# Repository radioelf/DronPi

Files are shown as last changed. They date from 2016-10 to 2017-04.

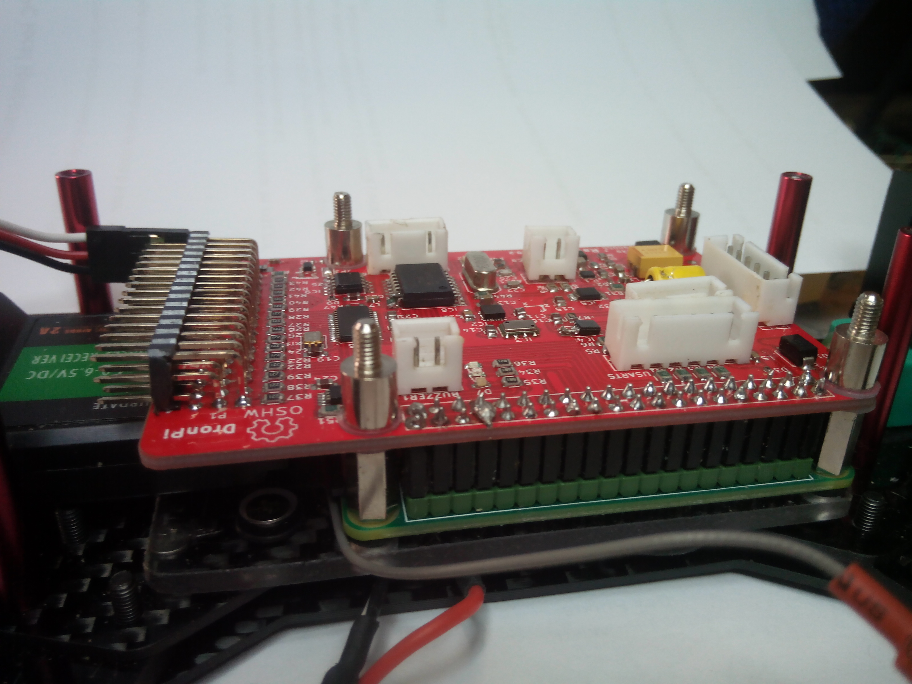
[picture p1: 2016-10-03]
images/IMG_20160930_155603.jpg

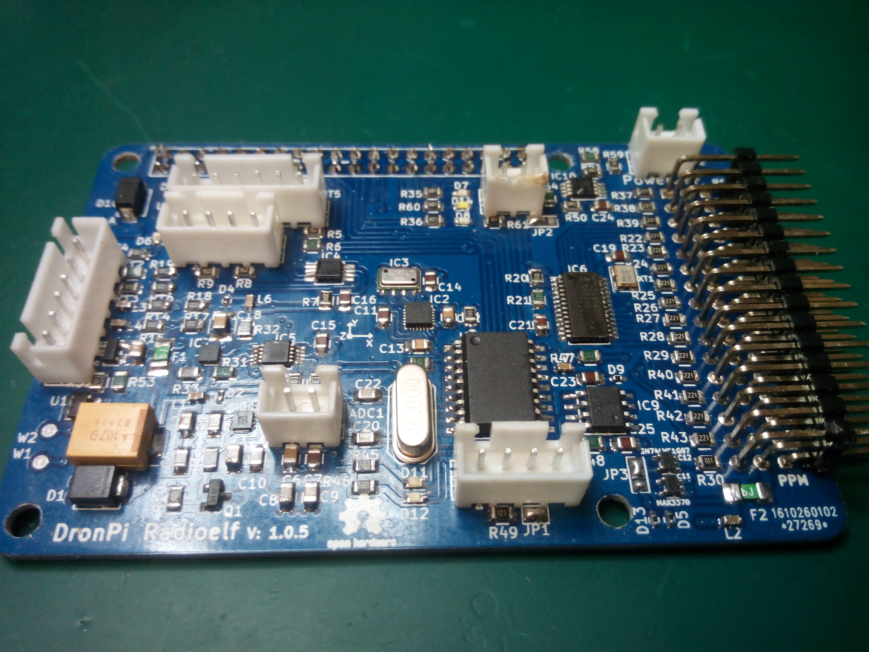
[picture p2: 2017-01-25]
images/IMG_20170104_161110.jpg

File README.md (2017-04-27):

# DronPi 
Placa sensores para [ardupilot](https://github.com/ArduPilot) y Raspberry o [DuePi](https://github.com/radioelf/Arduino-Due-mod-for-GPIO-compatible-Raspberry-Pi)

Sensores:  
    -***MS5611*** Sensor de presión barométrica (Bus SPI)   
    -***MPU9250*** 	Giroscopio/Acelerómetro/Compás interno/9-AXIS (Bus SPI)   
    -***MCP2515*** CAN Bus (Bus SPI)  
    -***ADS1115*** ADC 16bits (Bus I2C) dirección 0x48, canal 0 tensión, canal 1 intensidad  
    -***PCA9685*** Generador de PWM (Bus I2c) dirección 0x40 y 0x70(ALLCALL)

Periféricos: zumbador, RS-232, i2C, PowerOOF, PPM S-BUS, ADC, Can-Bus, HATs (Hardware Attached on Top)

http://radioelf.blogspot.com.es/  
https://www.youtube.com/watch?v=Fd6dcFx_-Ns (test..)

1/01/17
Changed IC12 SN74LVC1G07 by SN74AHC1G04 (to use S-bus)

## Creative Commons License Disclaimer

UNLESS OTHERWISE MUTUALLY AGREED TO BY THE PARTIES IN WRITING, LICENSOR OFFERS THE WORK AS-IS AND MAKES NO REPRESENTATIONS OR WARRANTIES OF ANY KIND CONCERNING THE WORK, EXPRESS, IMPLIED, STATUTORY OR OTHERWISE, INCLUDING, WITHOUT LIMITATION, WARRANTIES OF TITLE, MERCHANTIBILITY, FITNESS FOR A PARTICULAR PURPOSE, NONINFRINGEMENT, OR THE ABSENCE OF LATENT OR OTHER DEFECTS, ACCURACY, OR THE PRESENCE OF ABSENCE OF ERRORS, WHETHER OR NOT DISCOVERABLE. SOME JURISDICTIONS DO NOT ALLOW THE EXCLUSION OF IMPLIED WARRANTIES, SO SUCH EXCLUSION MAY NOT APPLY TO YOU. EXCEPT TO THE EXTENT REQUIRED BY APPLICABLE LAW, IN NO EVENT WILL LICENSOR BE LIABLE TO YOU ON ANY LEGAL THEORY FOR ANY SPECIAL, INCIDENTAL, CONSEQUENTIAL, PUNITIVE OR EXEMPLARY DAMAGES ARISING OUT OF THIS LICENSE OR THE USE OF THE WORK, EVEN IF LICENSOR HAS BEEN ADVISED OF THE POSSIBILITY OF SUCH DAMAGES.

http://creativecommons.org/licenses/by-sa/3.0/

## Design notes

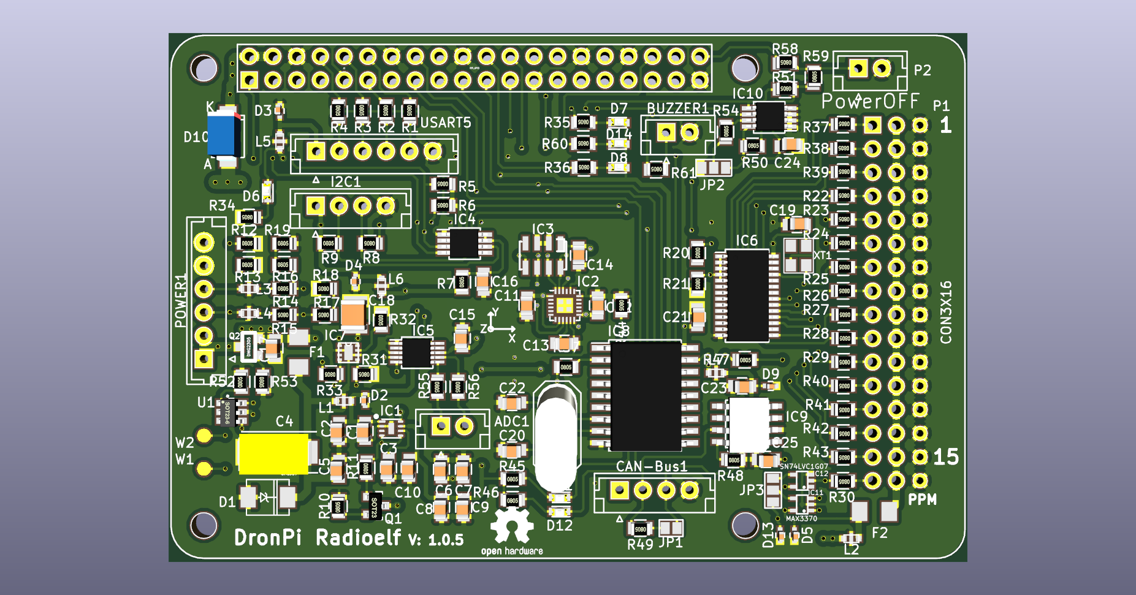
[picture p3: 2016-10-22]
images/dronPi.png

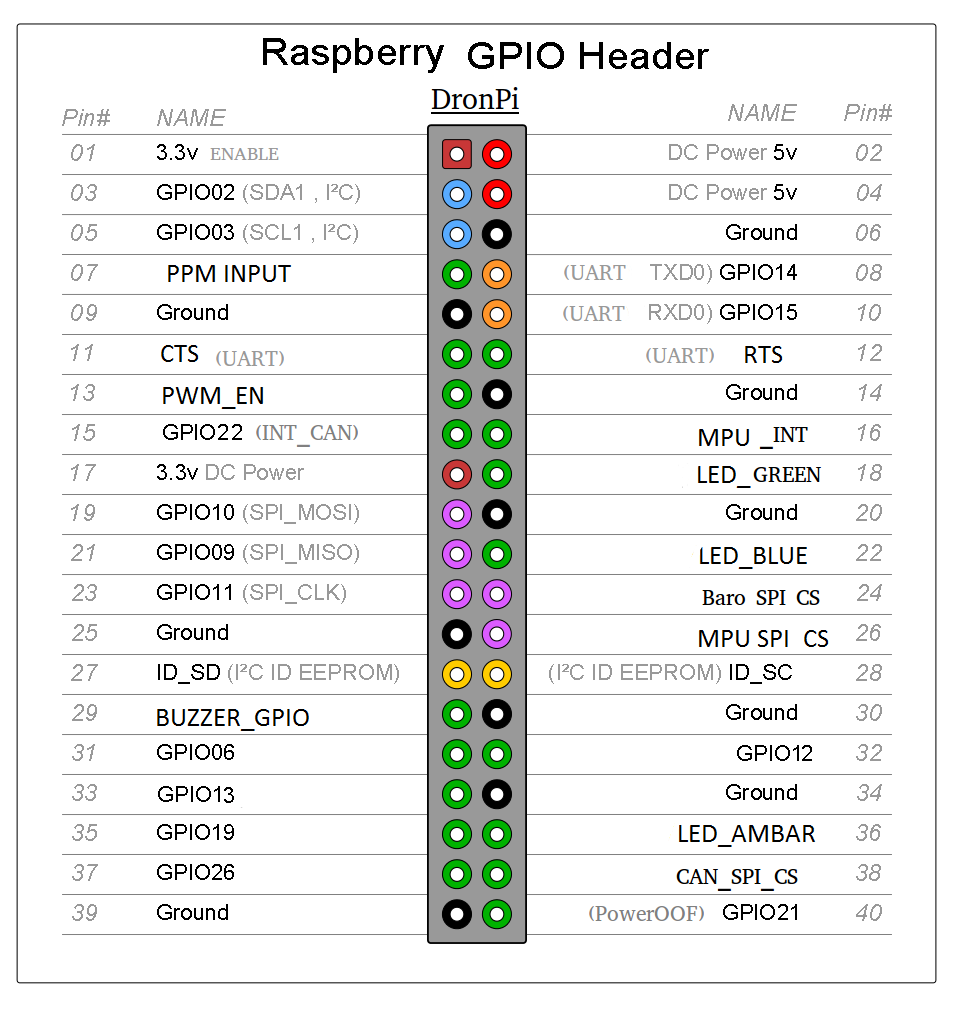
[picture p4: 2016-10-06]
images/GPIO_DronPi.png

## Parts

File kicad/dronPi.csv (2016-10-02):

Reference | Value | Footprint | Datasheet
M1 | OSHW-LOGOS | Symbols:OSHW-Logo2_7.3x6mm_SilkScreen
J1 | RPi_GPIO | dronpi:raspberrypi2
IC7 | BQ24315 | dronpi:BQ24313_DSG_8
R32 | 24K | Resistors_SMD:R_0805
R31 | 10K | Resistors_SMD:R_0805
R33 | 1M | Resistors_SMD:R_0805
C18 | 100uF | Capacitors_SMD:C_1210
W2 | REG_FAULT | Measurement_Points:Measurement_Point_Round-SMD-Pad_Small
W1 | REG_CE | Measurement_Points:Measurement_Point_Round-SMD-Pad_Small
IC4 | PCA9306 | Housings_SSOP:MSOP-8_3x3mm_Pitch0.65mm
R7 | 200K | Resistors_SMD:R_0805
R6 | 1K5 | Resistors_SMD:R_0805
R5 | 1K5 | Resistors_SMD:R_0805
R8 | 1K5 | Resistors_SMD:R_0805
R9 | 1K5 | Resistors_SMD:R_0805
C16 | 100nF | Capacitors_SMD:C_0805
D4 | PESD0402-140 | Capacitors_SMD:C_0402
L6 | KNH16C104DA5TS | dronpi:KYOCERA-KNH16-DA
I2C1 | JST_4PIN | Connectors_JST:JST_EH_B04B-EH-A_04x2.50mm_Straight
D1 | SMBJ5V | Tinkerforge:DO-214AA
C4 | 220uF | Capacitors_Tantalum_SMD:TantalC_SizeD_EIA-7343_Reflow
C5 | 100nF | Capacitors_SMD:C_0805
IC1 | MIC5332 | awallin:MLF-8-1EP
C3 | 2u2F | Capacitors_SMD:C_0805
C6 | 22uF | Capacitors_SMD:C_0805
C7 | 100nF | Capacitors_SMD:C_0805
C8 | 1uF | Capacitors_SMD:C_0805
C9 | 22uF | Capacitors_SMD:C_0805
C10 | 100nF | Capacitors_SMD:C_0805
C2 | 10uF | Capacitors_SMD:C_0805
C1 | 100nF | Capacitors_SMD:C_0805
F1 | 0ZCA0035FF2G | Fuse_Holders_and_Fuses:Fuse_SMD1206_Wave
L1 | KNH16C104DA5TS | dronpi:KYOCERA-KNH16-DA
L2 | KNH16C104DA5TS | dronpi:KYOCERA-KNH16-DA
D2 | PESD0402-140 | Capacitors_SMD:C_0402
D5 | PESD0402-140 | Capacitors_SMD:C_0402
Q1 | MMBT3906LT1 | TO_SOT_Packages_SMD:SOT-23
R11 | 1k8 | Resistors_SMD:R_0805
R10 | 10R | Resistors_SMD:R_0805
POWER1 | JST_6PIN | Connectors_JST:JST_EH_B06B-EH-A_06x2.50mm_Straight
C17 | 22uF | Capacitors_SMD:C_0805
Q2 | DMG2305 | Tinkerforge:SOT23-3
U1 | DMMT5401 | TO_SOT_Packages_SMD:SOT-23-6
R52 | 47k | Resistors_SMD:R_0805
R53 | 47K | Resistors_SMD:R_0805
D10 | STPS1L30A | Diodes_SMD:SMA_Standard
R59 | 10k | Resistors_SMD:R_0805
R58 | 1k | Resistors_SMD:R_0805
P2 | PowerOff | Connectors_JST:JST_EH_B02B-EH-A_02x2.50mm_Straight
IC5 | ADC_ADS1115 | Housings_SSOP:MSOP-10_3x3mm_Pitch0.5mm
C15 | 100nF | Capacitors_SMD:C_0805
L3 | KNH16C104DA5TS | dronpi:KYOCERA-KNH16-DA
L4 | KNH16C104DA5TS | dronpi:KYOCERA-KNH16-DA
R16 | 10K/0.1% | Resistors_SMD:R_0805
R14 | 10K/0.1% | Resistors_SMD:R_0805
R18 | 10K/0.1% | Resistors_SMD:R_0805
R17 | 10K/0.1% | Resistors_SMD:R_0805
R13 | 1M | Resistors_SMD:R_0805
R19 | 10K/0.1% | Resistors_SMD:R_0805
R12 | 1M | Resistors_SMD:R_0805
R15 | 10K/0.1% | Resistors_SMD:R_0805
R55 | 10K/0.1% | Resistors_SMD:R_0805
R56 | 10K/0.1% | Resistors_SMD:R_0805
ADC1 | CONN_01X02 | Connectors_JST:JST_EH_B02B-EH-A_02x2.50mm_Straight
IC2 | MPU-9250 | Housings_DFN_QFN:QFN-24-1EP_3x3mm_Pitch0.4mm
C13 | 2u2 | Capacitors_SMD:C_0805
C11 | 100nF | Capacitors_SMD:C_0805
C12 | 10nF | Capacitors_SMD:C_0805
IC3 | MS5611-01BA | Tinkerforge:MS5611
C14 | 100nF | Capacitors_SMD:C_0805
D7 | LED_verde | LEDs:LED_0603
D8 | LED_azul | LEDs:LED_0603
R34 | 680 | Resistors_SMD:R_0805
R35 | 680 | Resistors_SMD:R_0805
R36 | 820 | Resistors_SMD:R_0805
D9 | PESD0402-140 | Capacitors_SMD:C_0402
L7 | KNH16C104DA5TS | dronpi:KYOCERA-KNH16-DA
IC9 | MCP2551 | SMD_Packages:SOIC-8-N
C23 | 100nF | Capacitors_SMD:C_0805
C21 | 100nF | Capacitors_SMD:C_0805
R45 | 560 | Resistors_SMD:R_0805
R49 | 120R | Resistors_SMD:R_0805
JP1 | JUMPER | Connect:GS2
CAN-Bus1 | JST_4PIN | Connectors_JST:JST_EH_B04B-EH-A_04x2.50mm_Straight
C22 | 22pF | Capacitors_SMD:C_0805
C20 | 22pF | Capacitors_SMD:C_0805
IC8 | MCP2515 | Tinkerforge:SOIC-18
R46 | 560 | Resistors_SMD:R_0805
D11 | verde | LEDs:LED_0603
D12 | Rojo | LEDs:LED_0603
R48 | 1K | Resistors_SMD:R_0805
R47 | 10K | Resistors_SMD:R_0805
XT2 | 16Mhz | Crystals:HC-18UV
BUZZER1 | CONN_01X04 | Connectors_JST:JST_EH_B02B-EH-A_02x2.50mm_Straight
IC10 | 24AA32 | Housings_SSOP:MSOP-8_3x3mm_Pitch0.65mm
C24 | 100nF | Capacitors_SMD:C_0805
R50 | 3K9 | Resistors_SMD:R_0805
R51 | 3k9 | Resistors_SMD:R_0805
D6 | LED_rojo | LEDs:LED_0603
JP2 | JUMPER3 | Connect:GS3
R54 | 1K | Resistors_SMD:R_0805
R44 | 18K | Resistors_SMD:R_0805
R57 | 10k | Resistors_SMD:R_0805
D14 | LED_naranja | LEDs:LED_0603
R60 | 680 | Resistors_SMD:R_0805
IC6 | PCA9685 | Housings_SSOP:TSSOP-28_4.4x9.7mm_Pitch0.65mm | DOCUMENTATION
R22 | 220 | Resistors_SMD:R_0805
R23 | 220 | Resistors_SMD:R_0805
R24 | 220 | Resistors_SMD:R_0805
R29 | 220 | Resistors_SMD:R_0805
R28 | 220 | Resistors_SMD:R_0805
R27 | 220 | Resistors_SMD:R_0805
R26 | 220 | Resistors_SMD:R_0805
R25 | 220 | Resistors_SMD:R_0805
R20 | 10K | Resistors_SMD:R_0805
R21 | 10K | Resistors_SMD:R_0805
XT1 | CRYSTAL_ASE-25mhz | dronpi:ASEseries
C19 | 100nF | Capacitors_SMD:C_0805
R39 | 220 | Resistors_SMD:R_0805
R38 | 220 | Resistors_SMD:R_0805
R37 | 220 | Resistors_SMD:R_0805
R40 | 220 | Resistors_SMD:R_0805
R41 | 220 | Resistors_SMD:R_0805
R42 | 220 | Resistors_SMD:R_0805
R43 | 220 | Resistors_SMD:R_0805
F2 | 0ZCA0035FF2G | Fuse_Holders_and_Fuses:Fuse_SMD1206_Wave
IC12 | SN74LVC1G07 | Tinkerforge:SC70-5
JP3 | JUMPER3 | Connect:GS3
D13 | PESD0402-140 | Capacitors_SMD:C_0402
R30 | 100 | Resistors_SMD:R_0805
IC11 | MAX3370 | Tinkerforge:SC70-5
C25 | 100nF | Capacitors_SMD:C_0805
P1 | CONN_3X16 | conector_3X16:IDC_Header_Straight_48pins
R4 | 120R | Resistors_SMD:R_0805
R3 | 120R | Resistors_SMD:R_0805
R1 | 120R | Resistors_SMD:R_0805
R2 | 120R | Resistors_SMD:R_0805
D3 | PESD0402-140 | Capacitors_SMD:C_0402
L5 | KNH16C104DA5TS | dronpi:KYOCERA-KNH16-DA
USART5 | JST_6PIN | Connectors_JST:JST_EH_B06B-EH-A_06x2.50mm_Straight

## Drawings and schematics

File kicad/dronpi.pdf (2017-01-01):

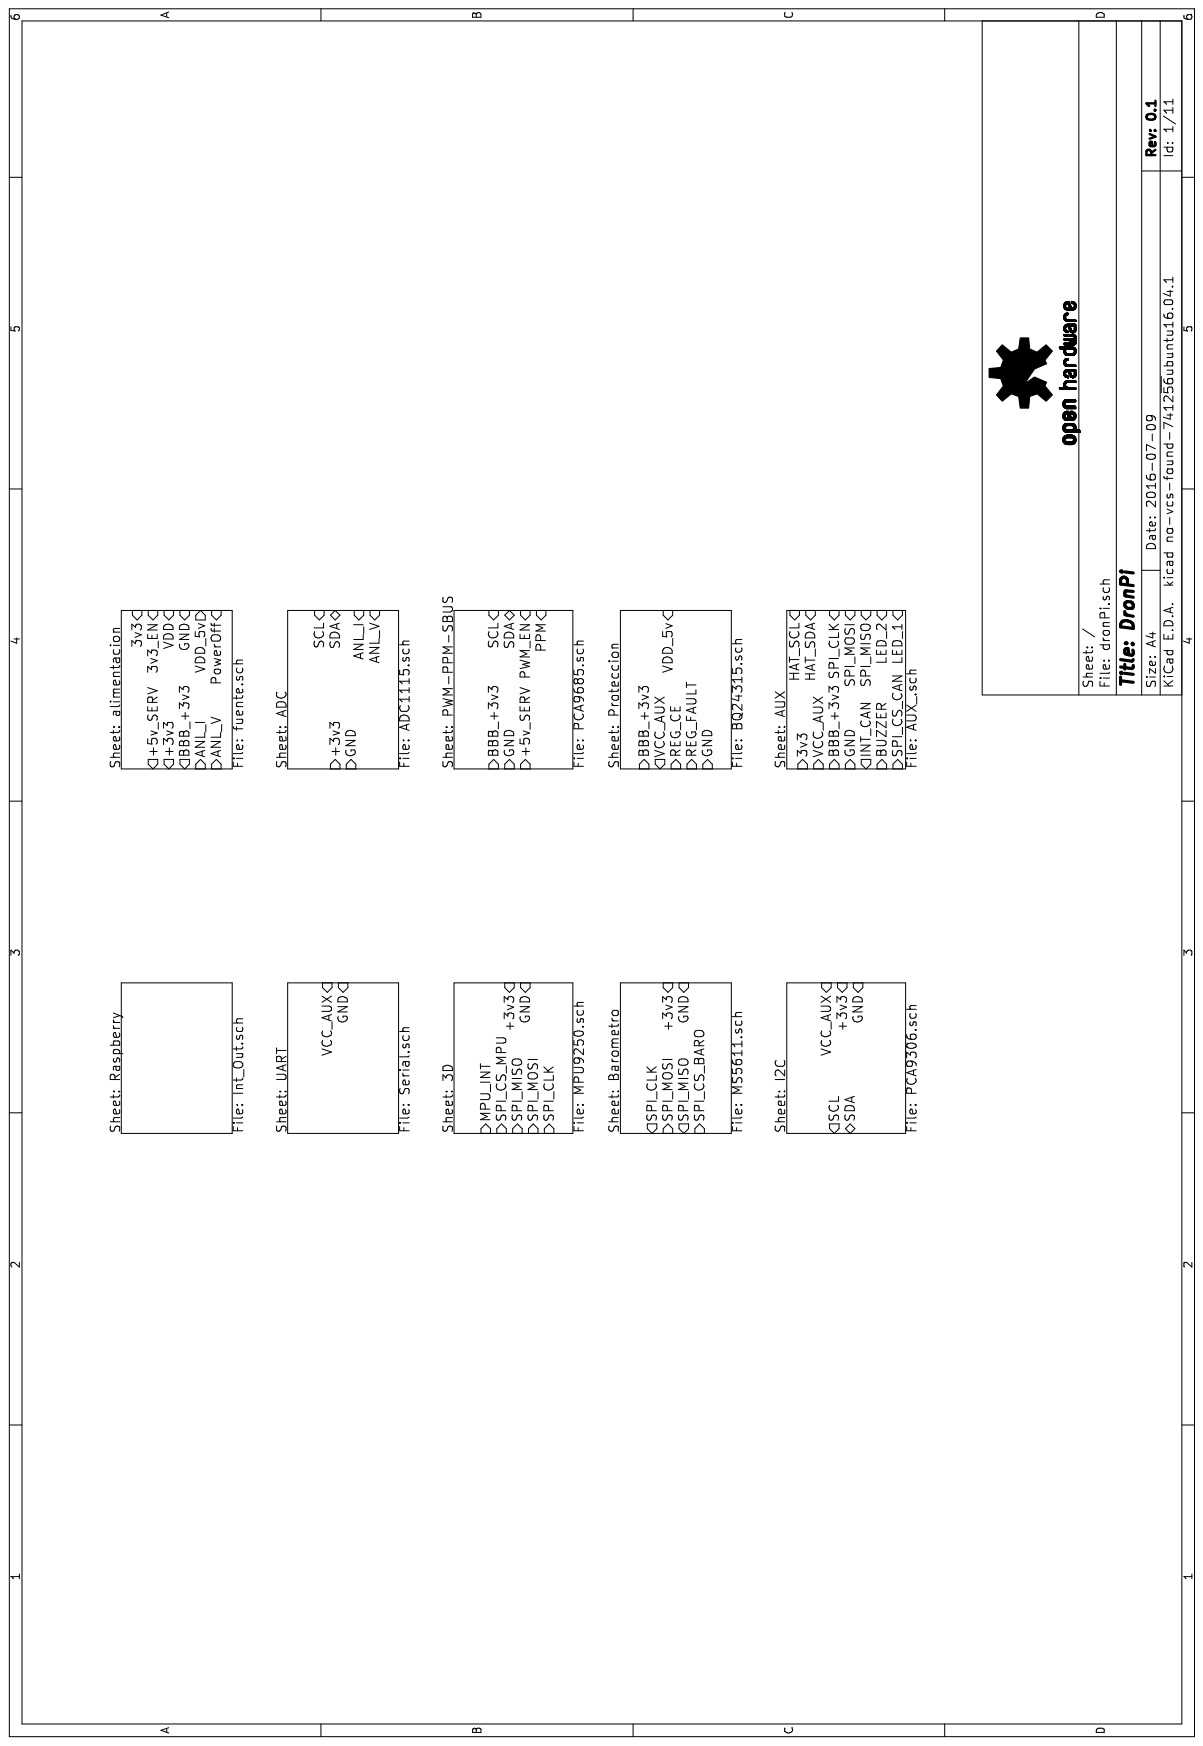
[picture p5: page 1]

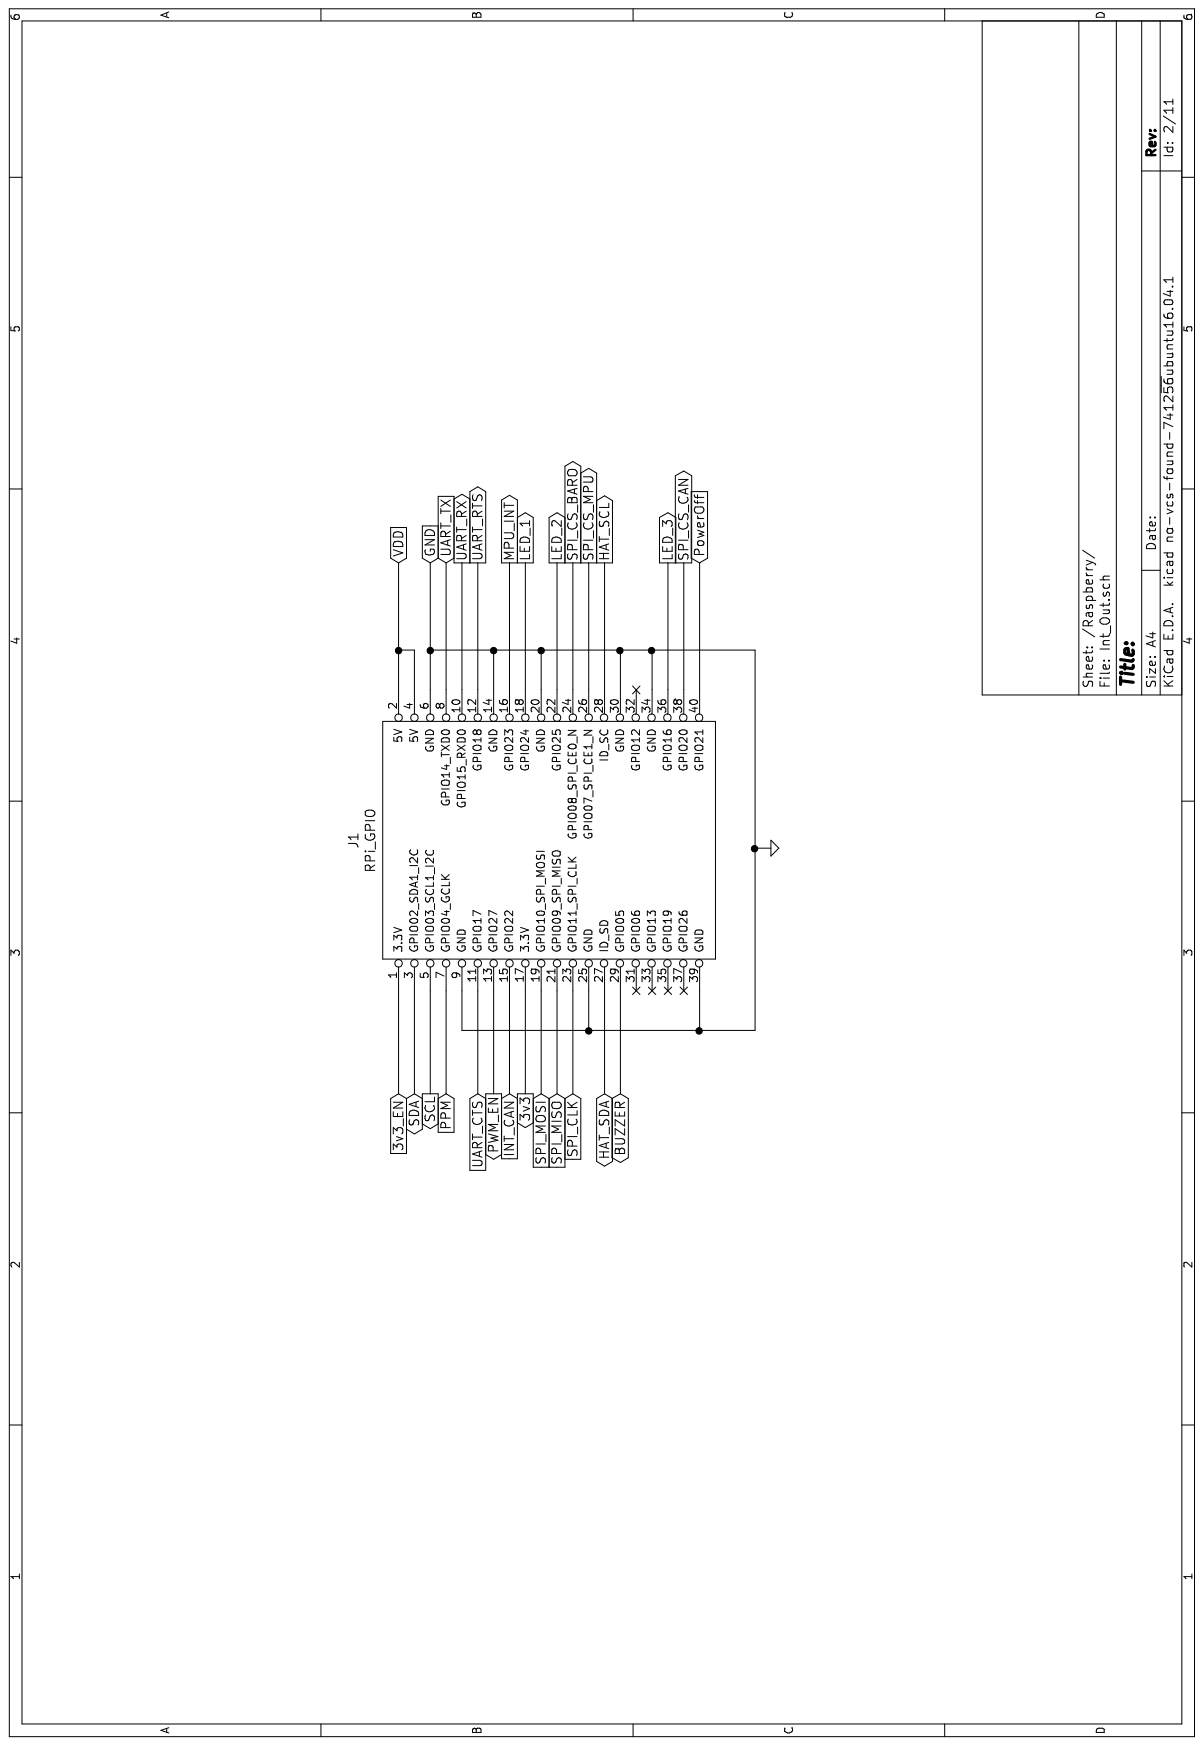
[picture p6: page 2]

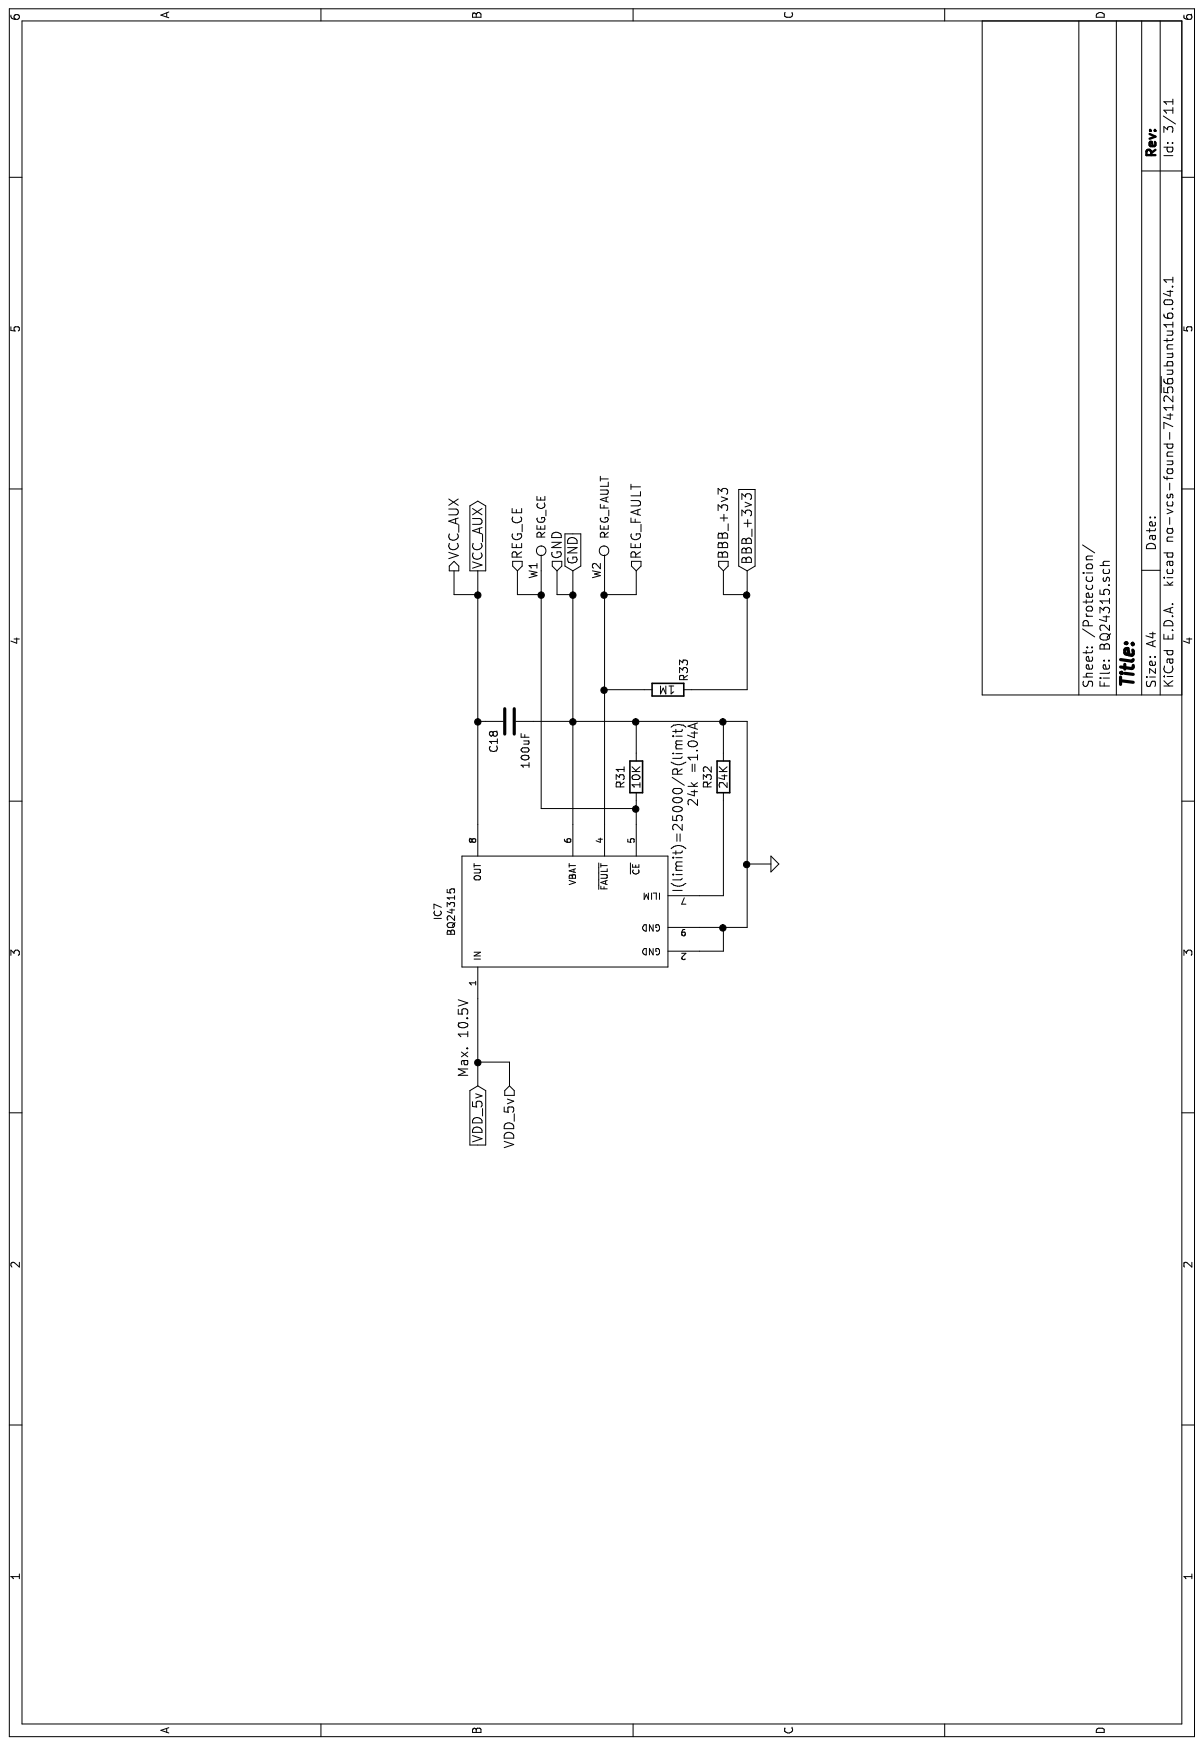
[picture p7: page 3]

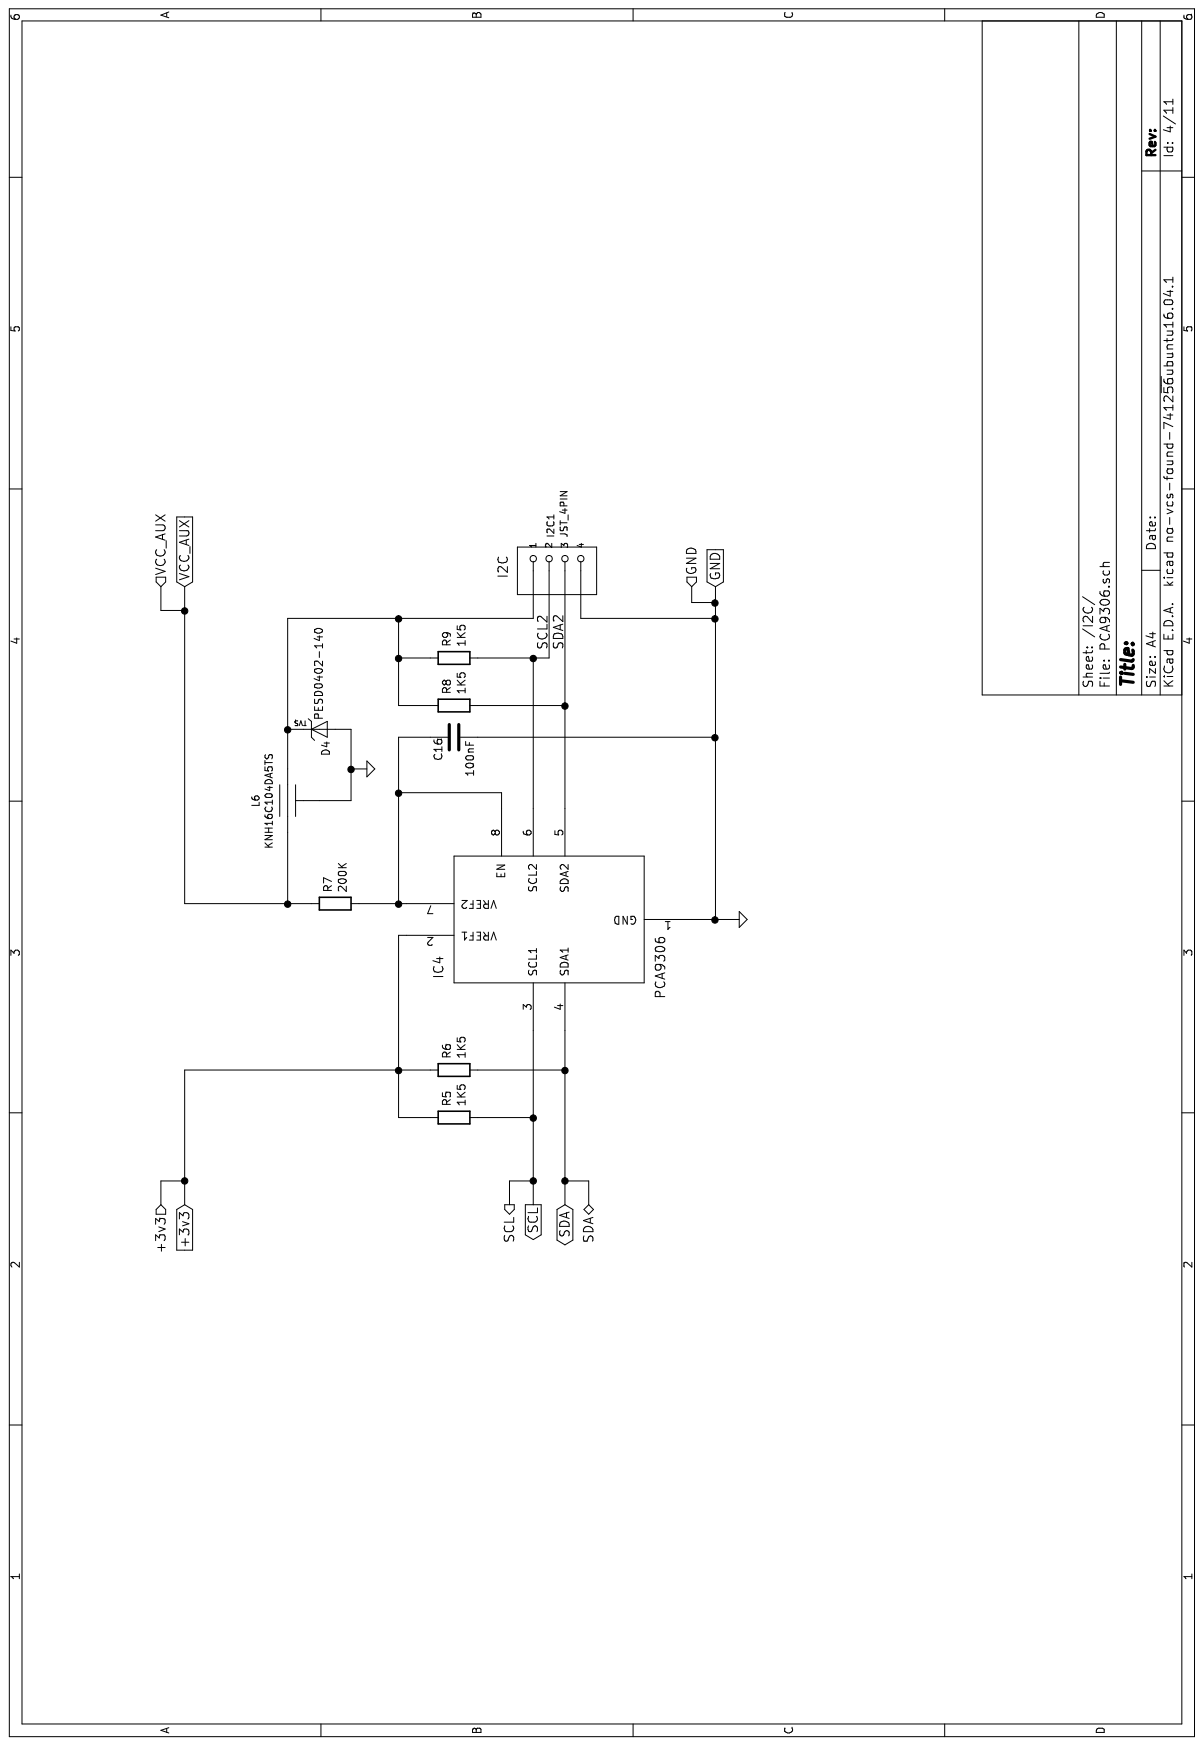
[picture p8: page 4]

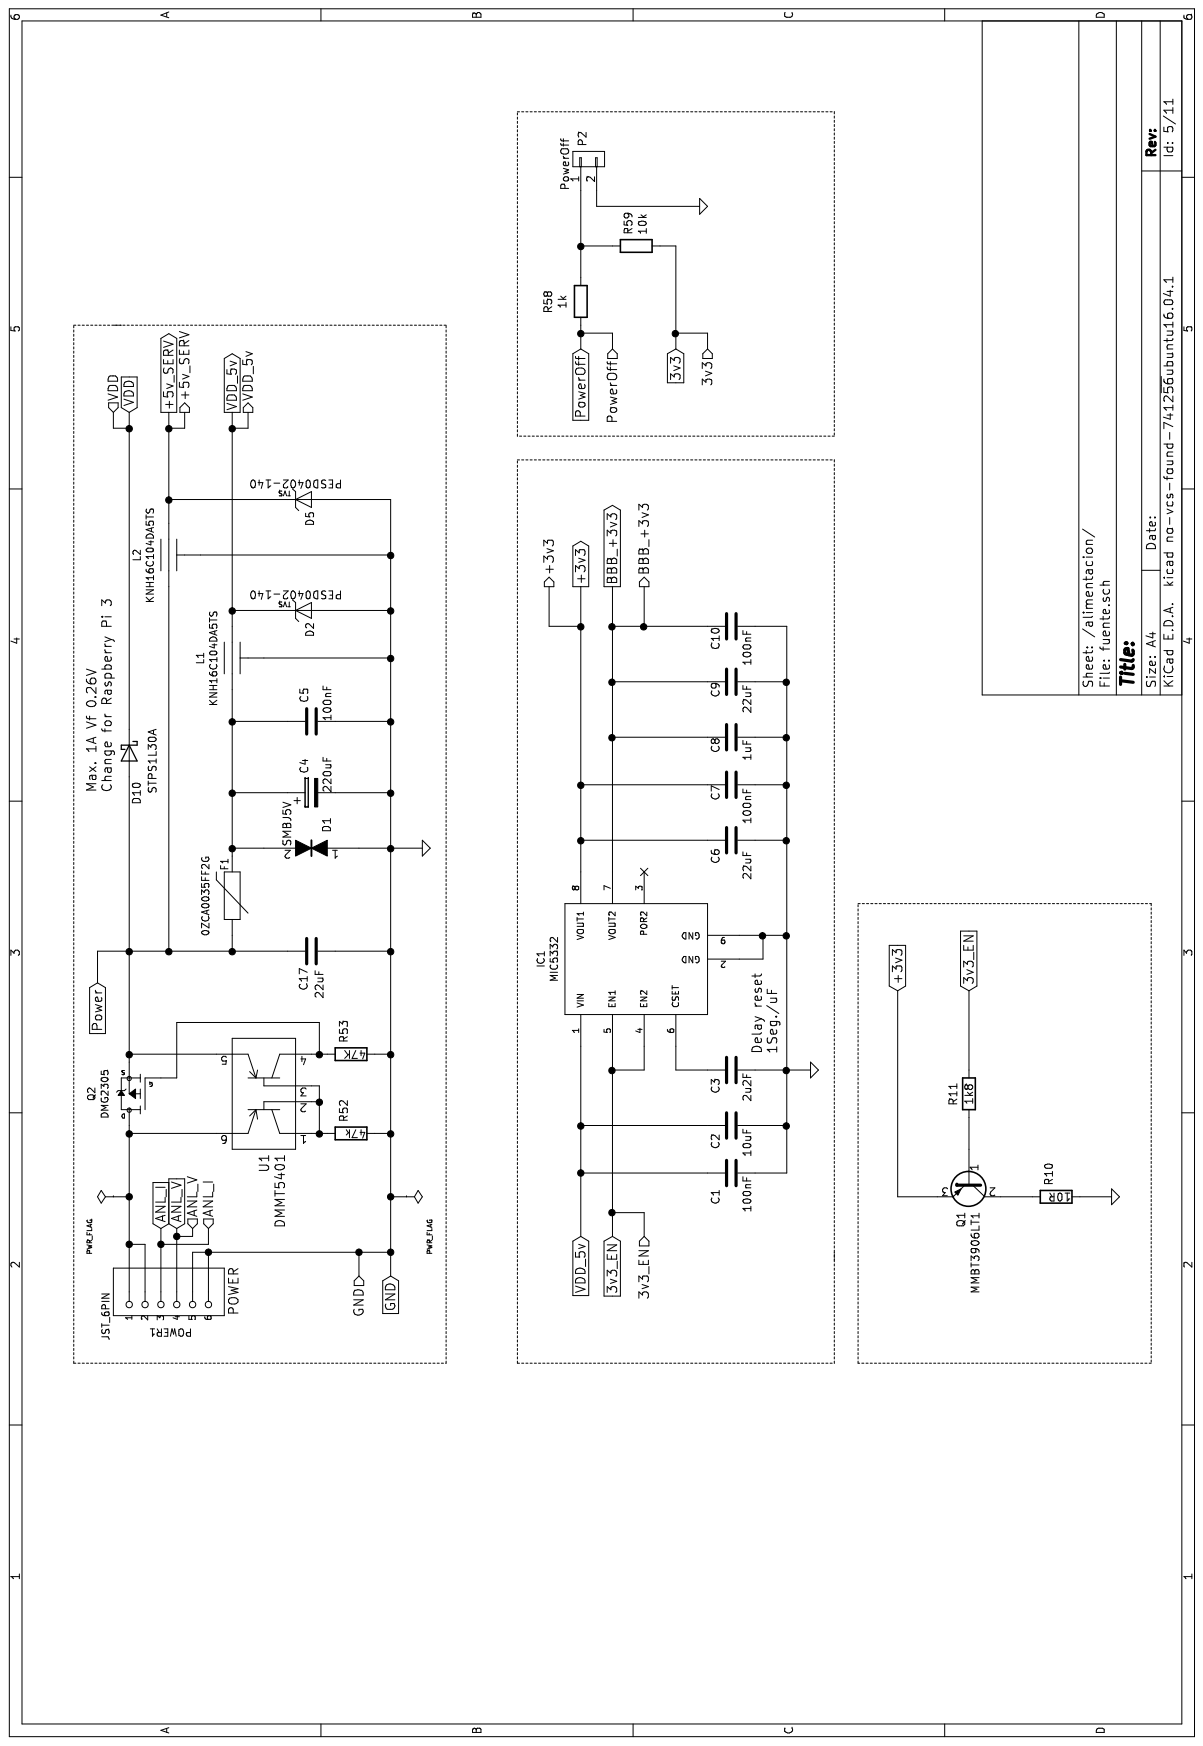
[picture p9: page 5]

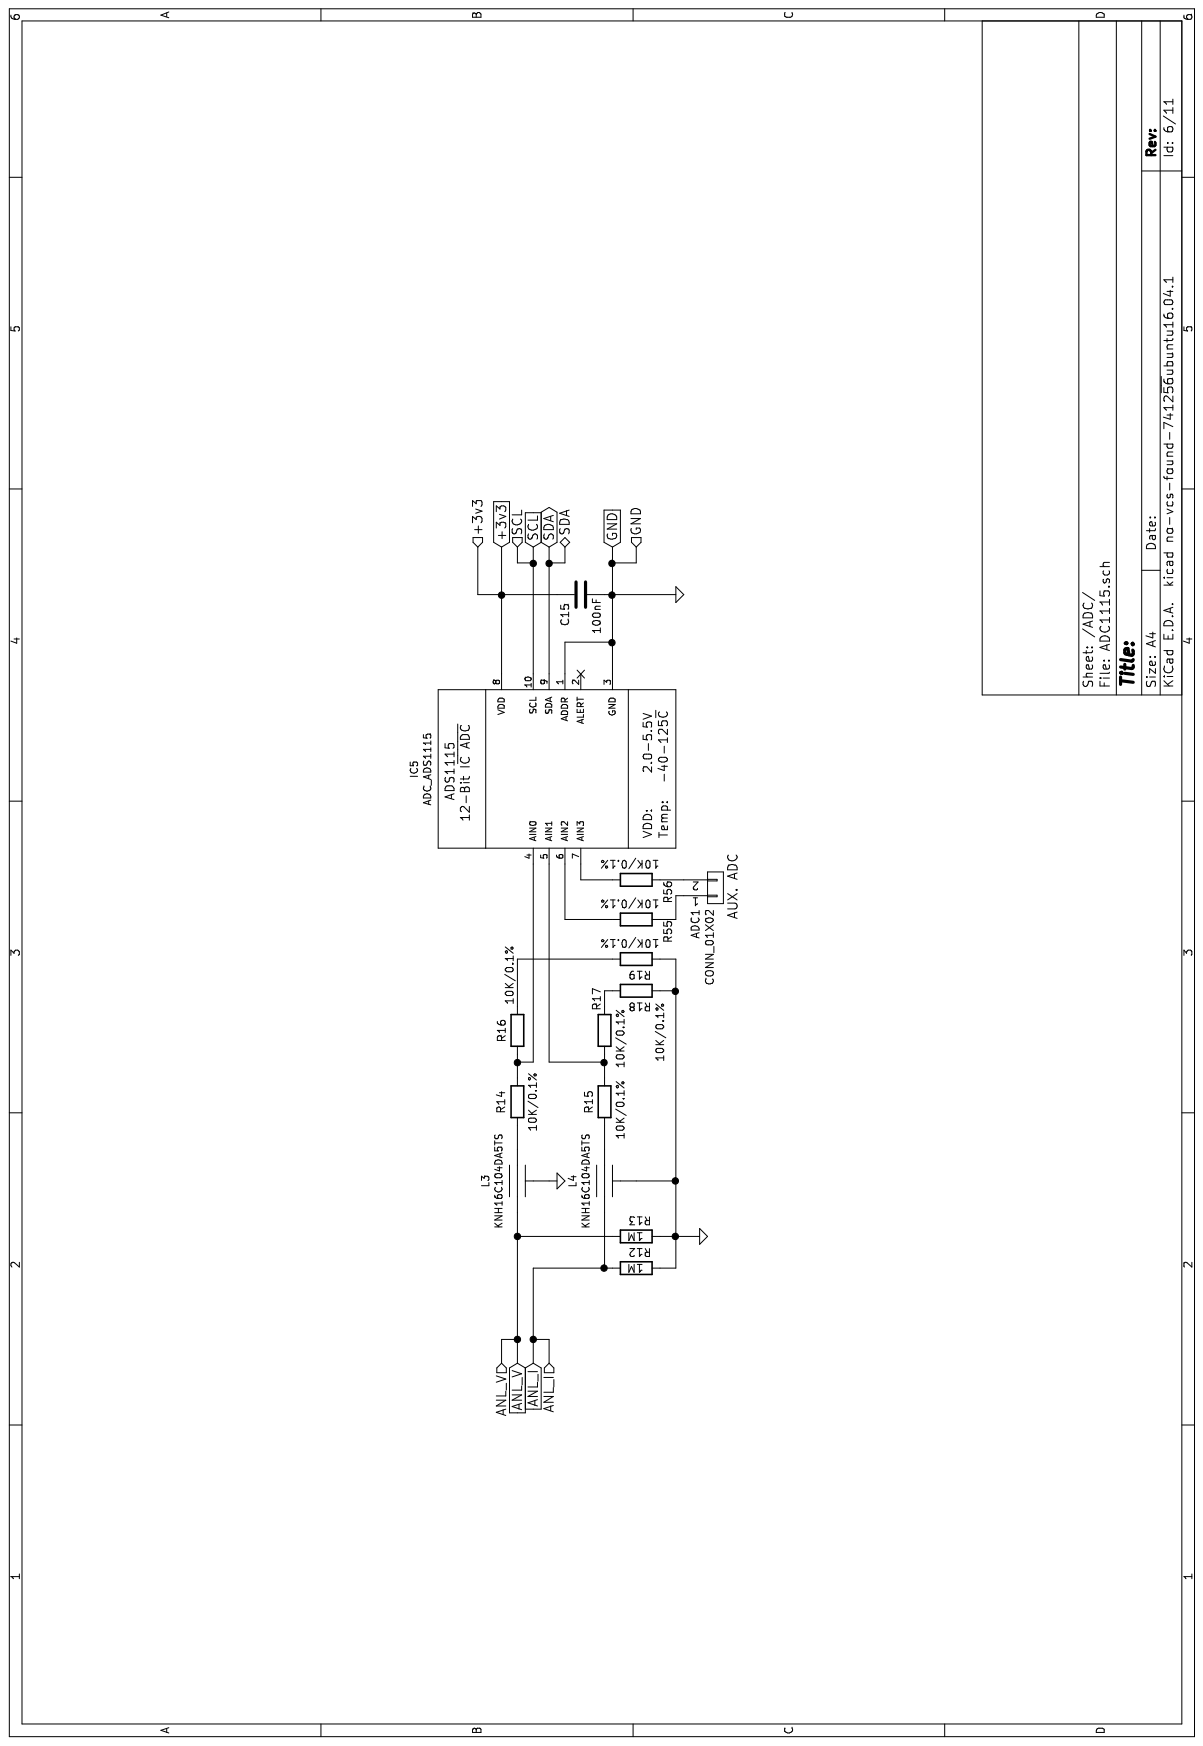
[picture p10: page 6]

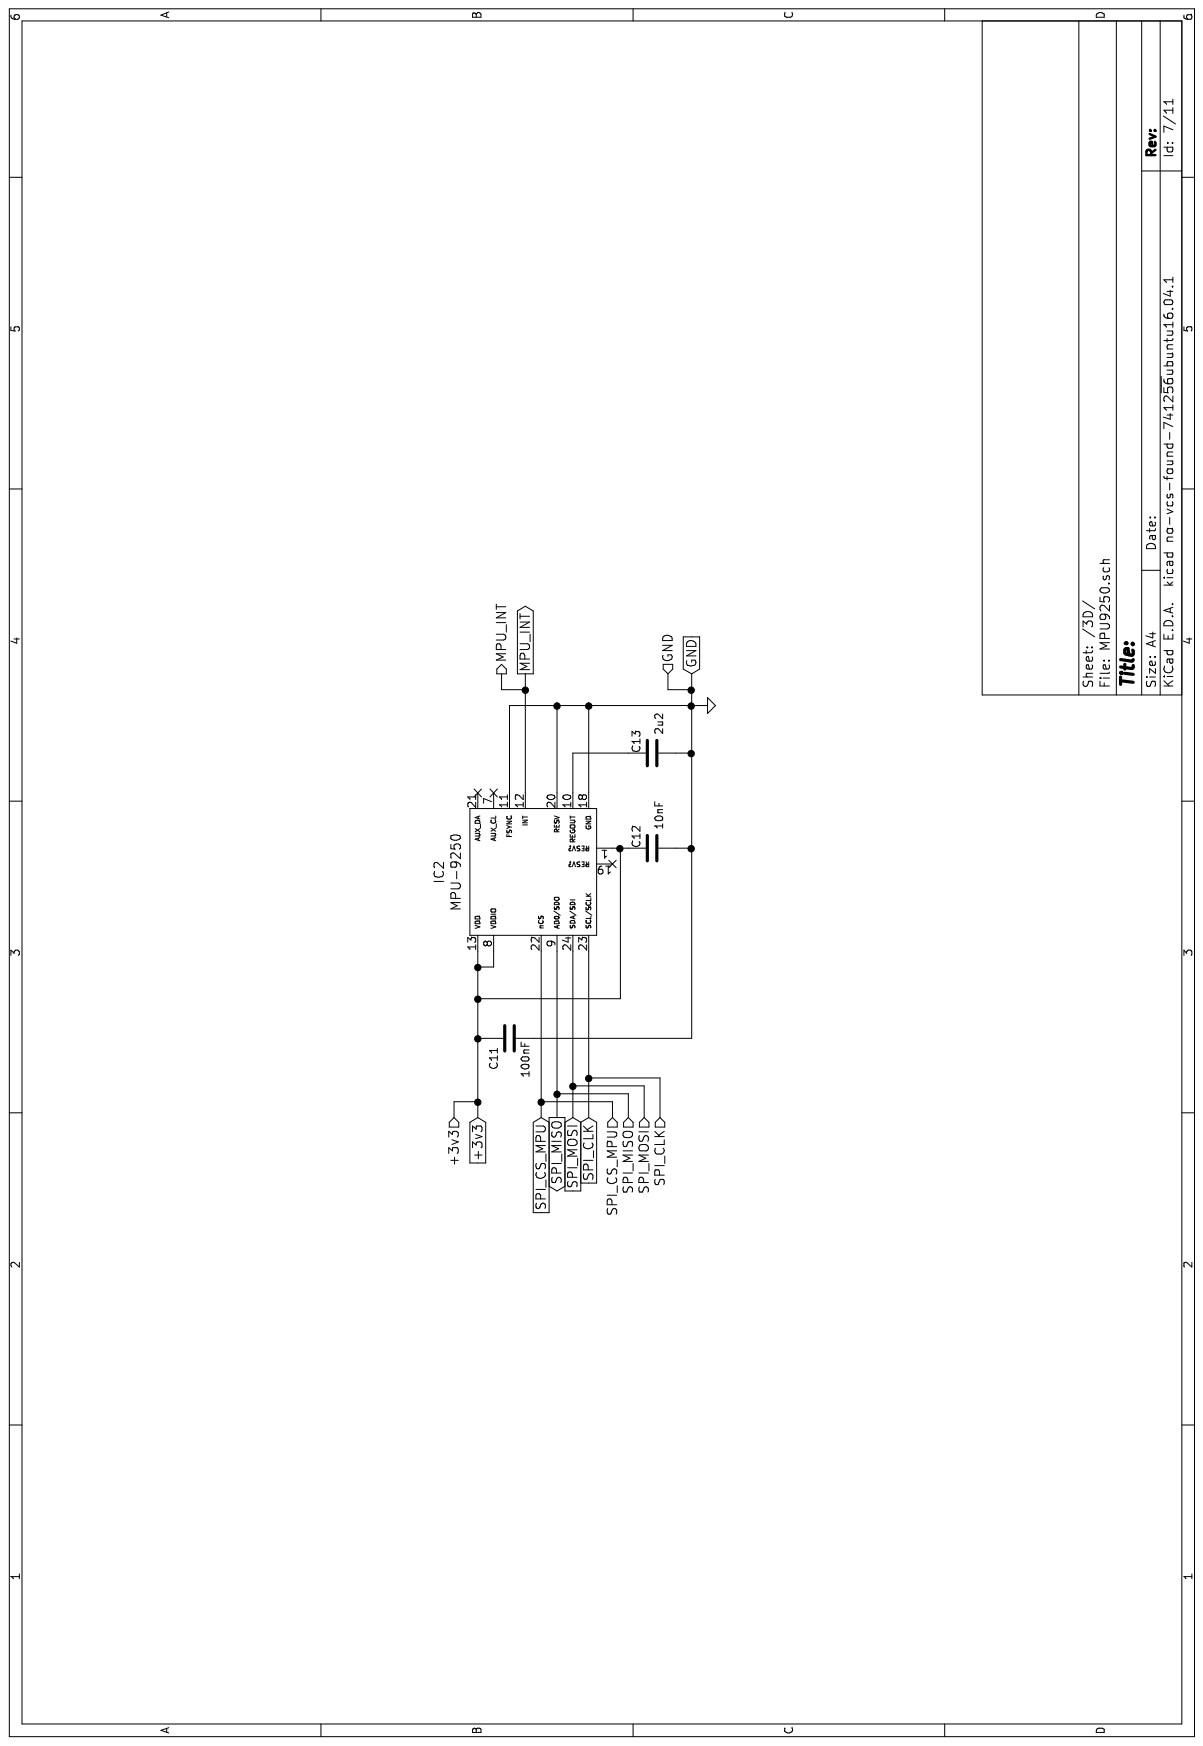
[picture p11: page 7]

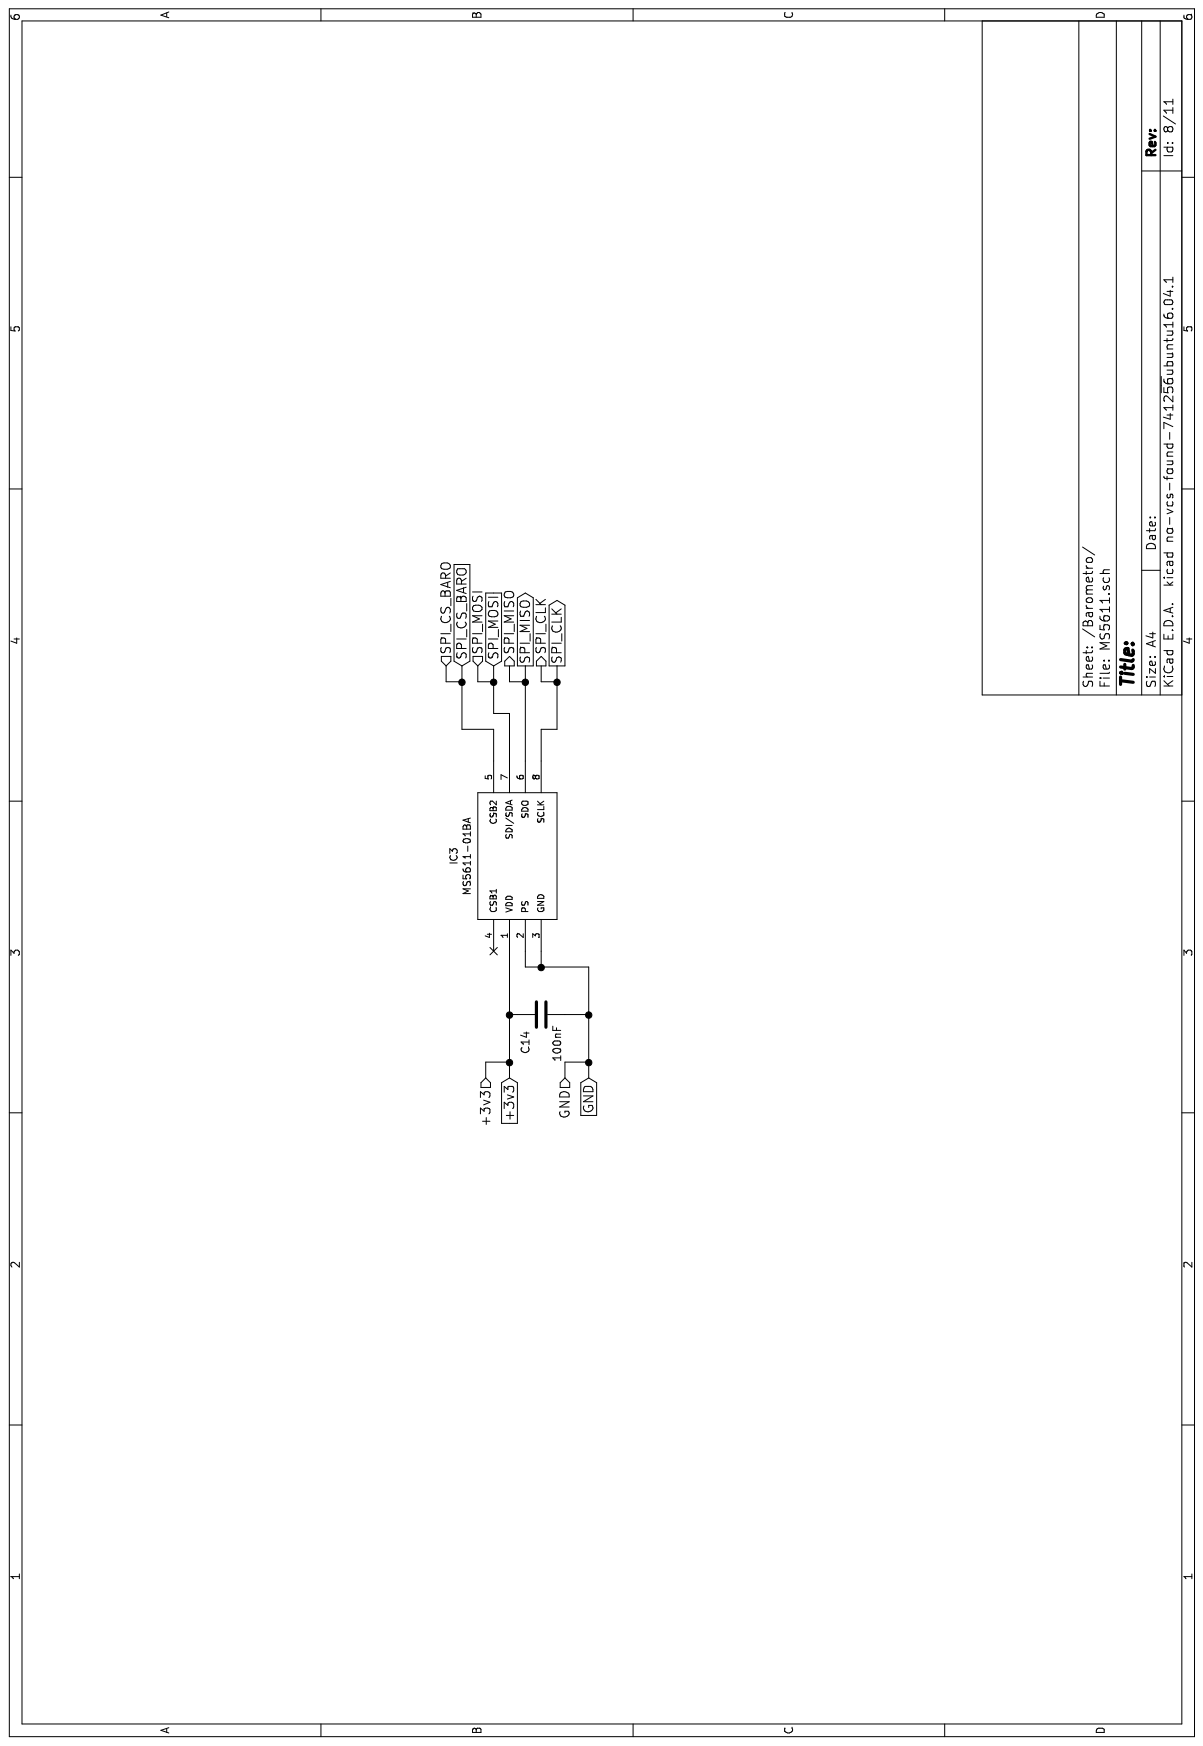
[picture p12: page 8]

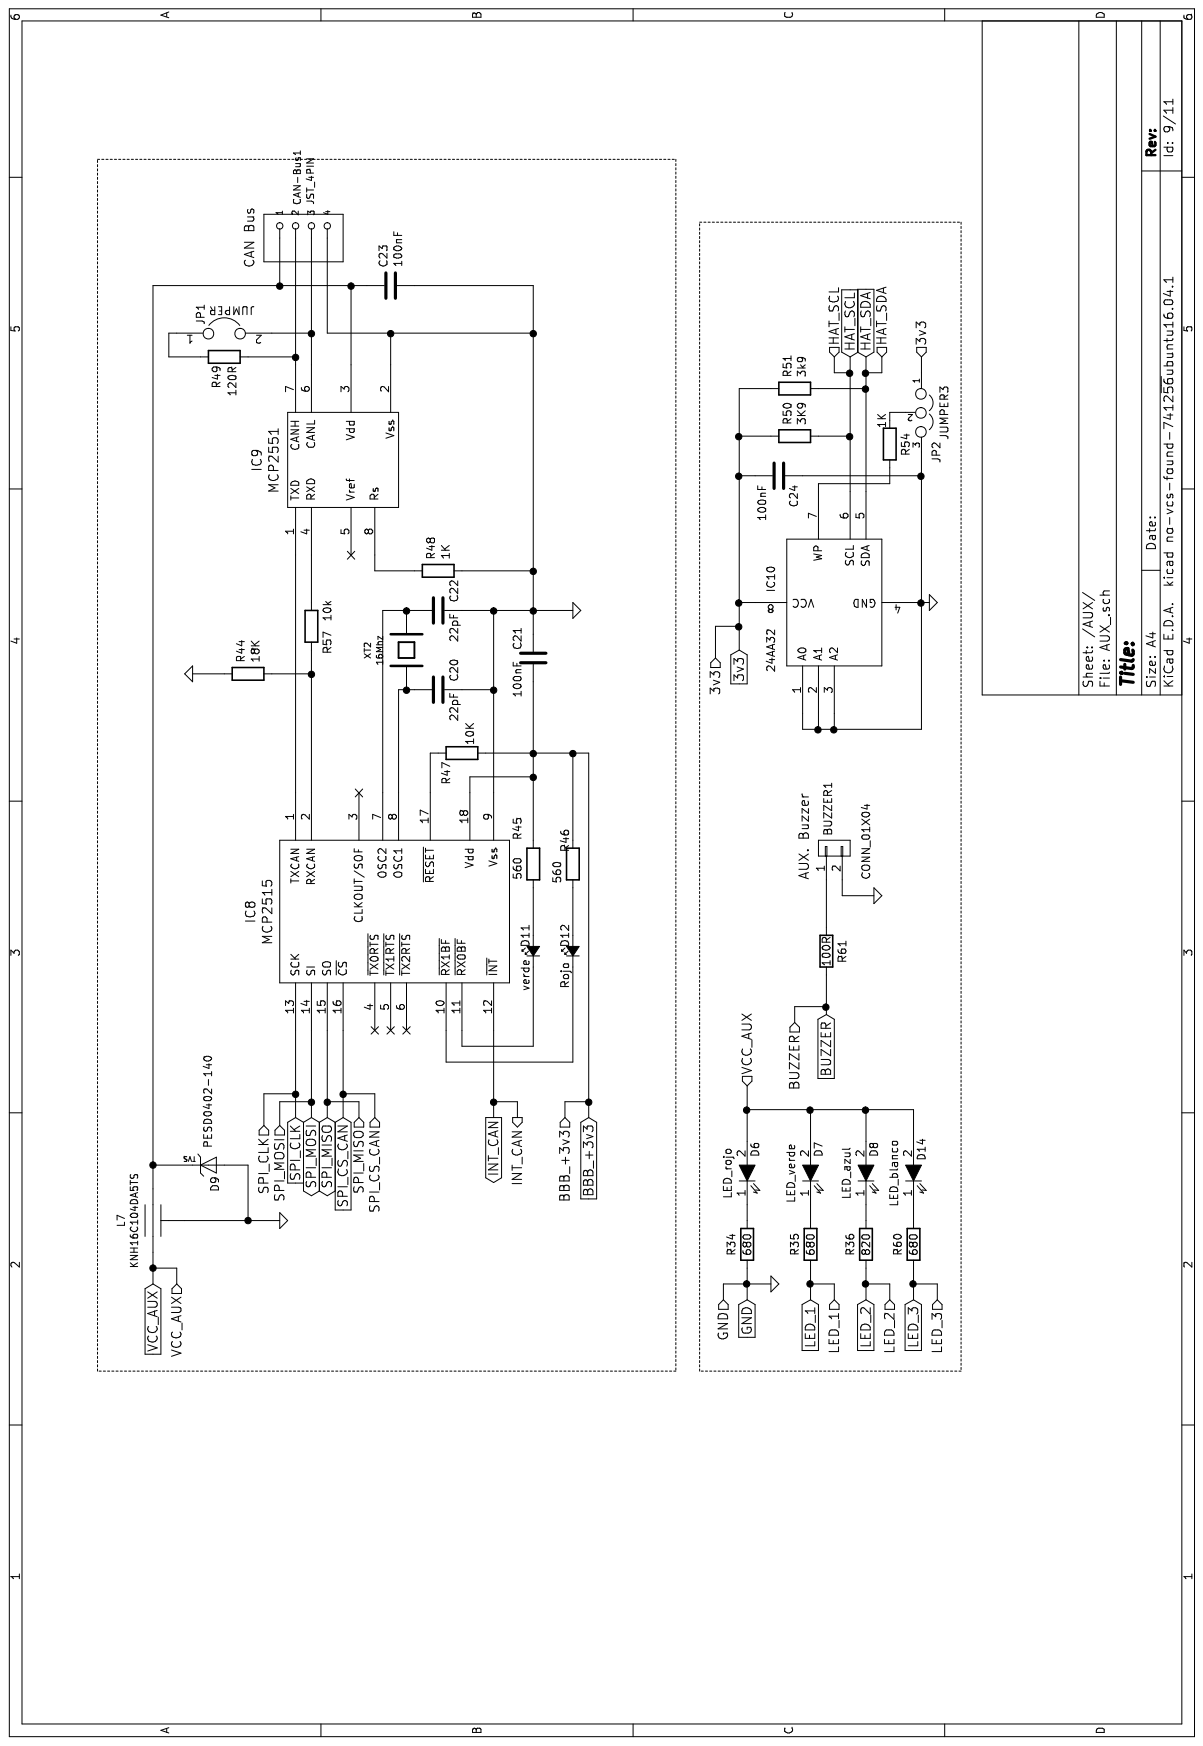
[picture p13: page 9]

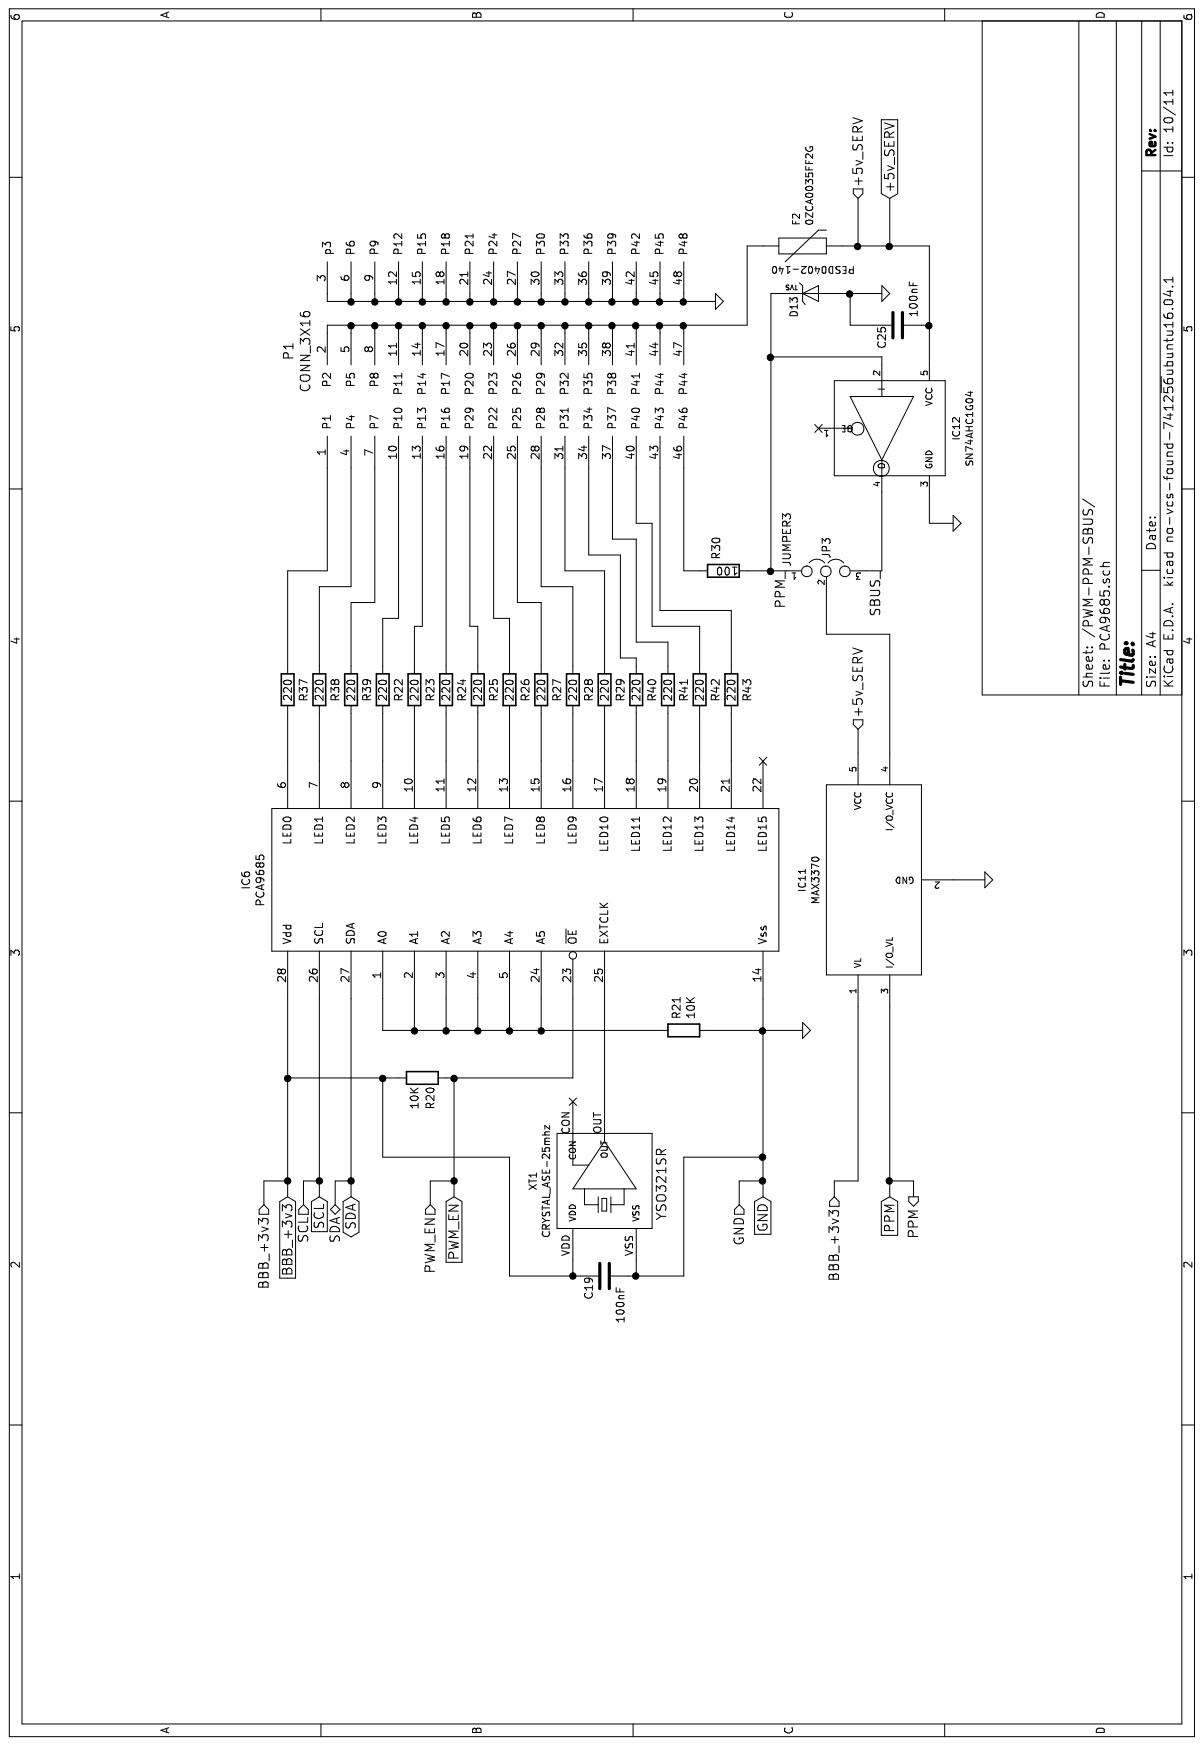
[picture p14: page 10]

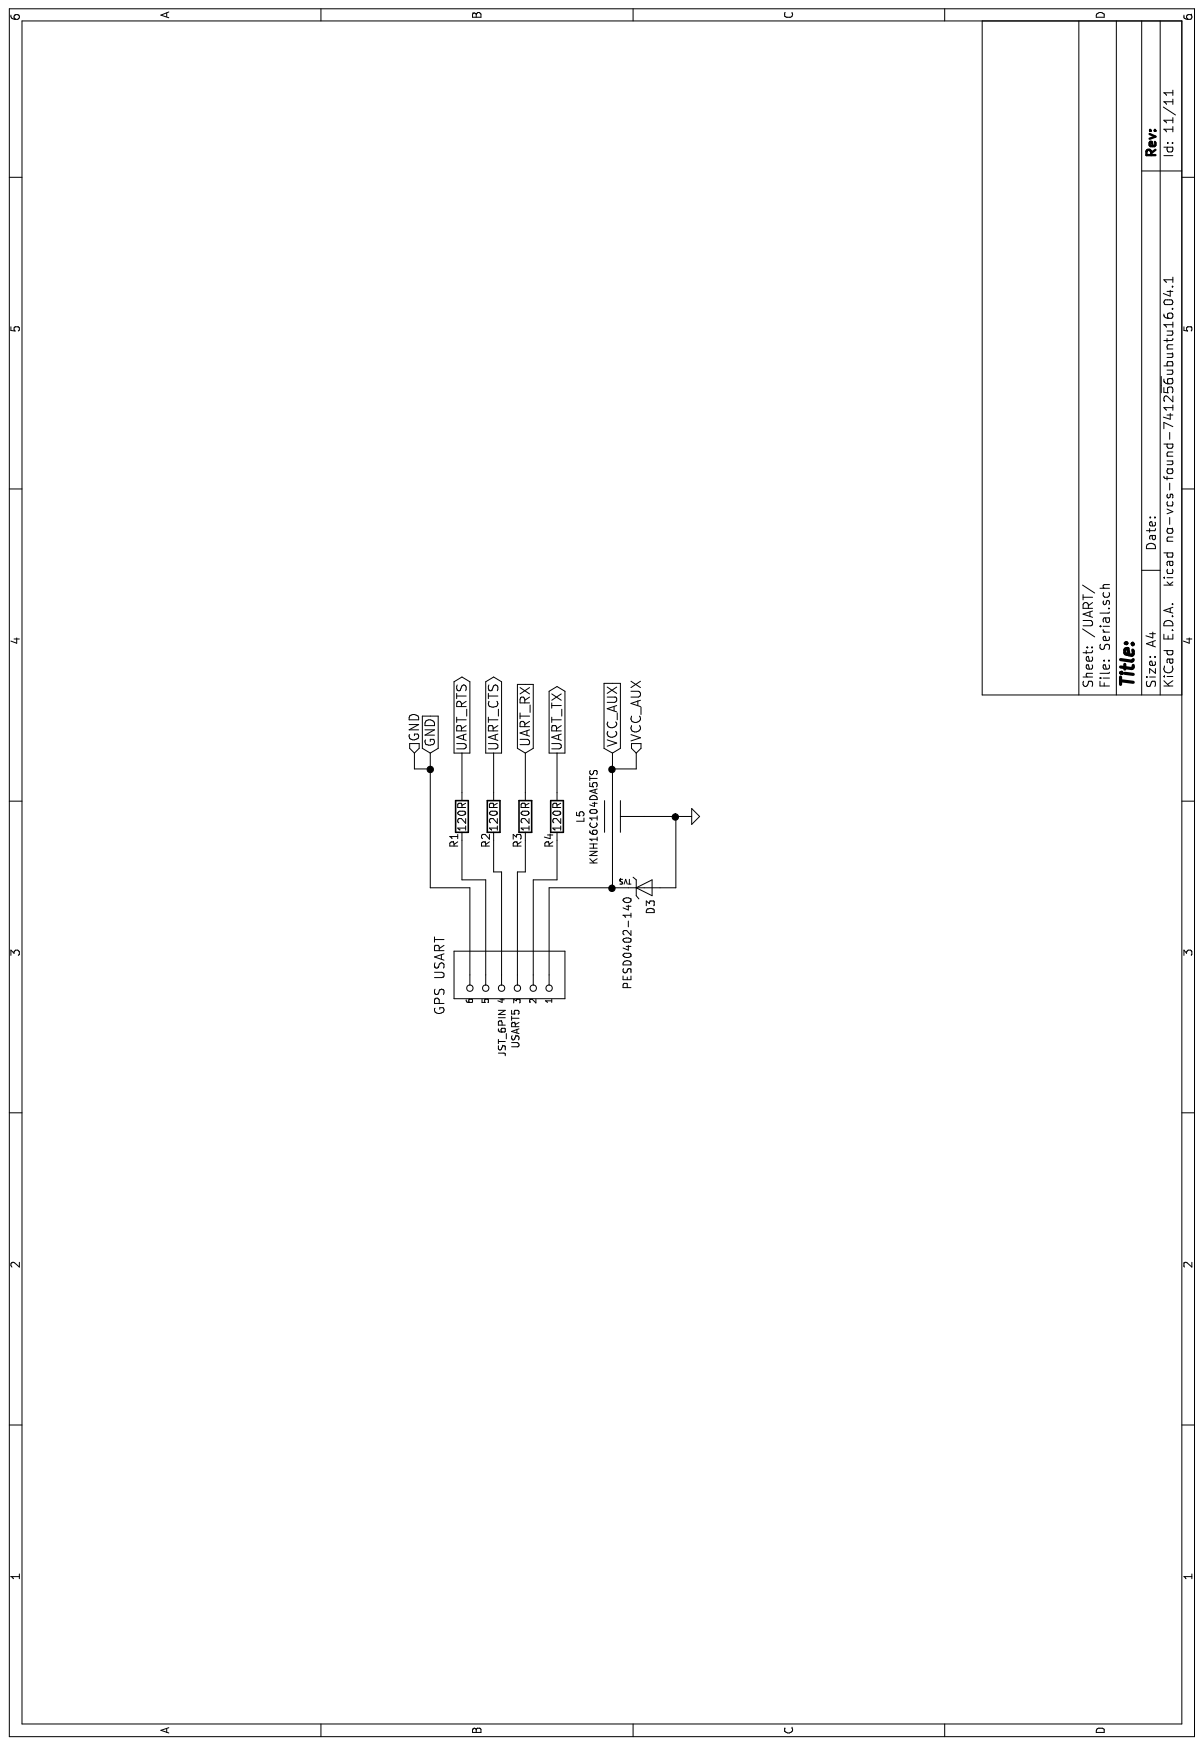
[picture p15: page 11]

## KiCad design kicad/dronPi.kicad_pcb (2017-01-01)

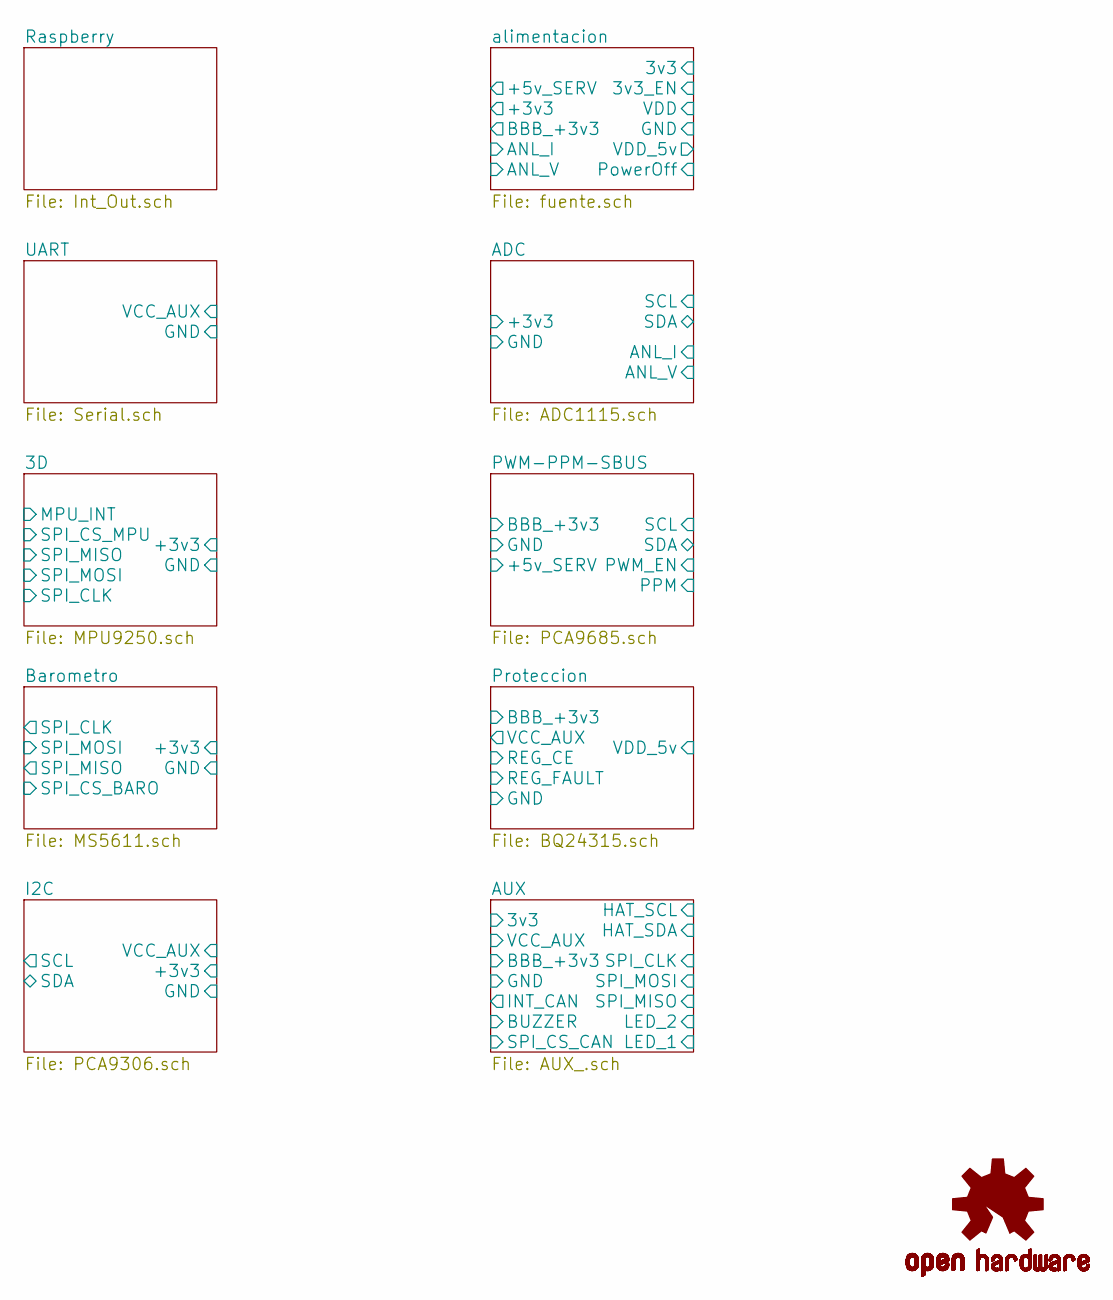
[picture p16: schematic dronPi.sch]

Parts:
M1: OSHW-LOGOS; OSHW-Logo2_7.3x6mm_SilkScreen

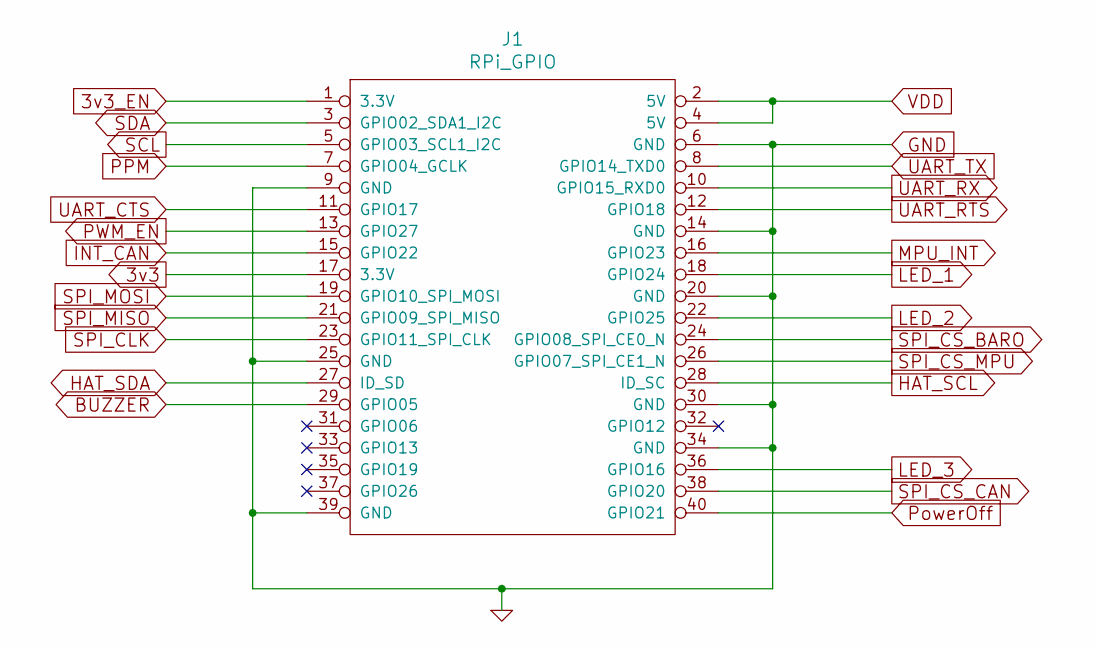
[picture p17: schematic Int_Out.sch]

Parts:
J1: RPi_GPIO; raspberrypi2

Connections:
3v3: J1.17 (3.3V); also elsewhere on the board
3v3_EN: J1.1 (3.3V); also elsewhere on the board
BUZZER: J1.29 (GPIO05); also elsewhere on the board
HAT_SCL: J1.28 (ID_SC); also elsewhere on the board
HAT_SDA: J1.27 (ID_SD); also elsewhere on the board
INT_CAN: J1.15 (GPIO22); also elsewhere on the board
LED_1: J1.18 (GPIO24); also elsewhere on the board
LED_2: J1.22 (GPIO25); also elsewhere on the board
LED_3: J1.36 (GPIO16); also elsewhere on the board
MPU_INT: J1.16 (GPIO23); also elsewhere on the board
PPM: J1.7 (GPIO04_GCLK); also elsewhere on the board
PWM_EN: J1.13 (GPIO27); also elsewhere on the board
PowerOff: J1.40 (GPIO21); also elsewhere on the board
SCL: J1.5 (GPIO03_SCL1_I2C); also elsewhere on the board
SDA: J1.3 (GPIO02_SDA1_I2C); also elsewhere on the board
SPI_CLK: J1.23 (GPIO11_SPI_CLK); also elsewhere on the board
SPI_CS_BARO: J1.24 (GPIO08_SPI_CE0_N); also elsewhere on the board
SPI_CS_CAN: J1.38 (GPIO20); also elsewhere on the board
SPI_CS_MPU: J1.26 (GPIO07_SPI_CE1_N); also elsewhere on the board
SPI_MISO: J1.21 (GPIO09_SPI_MISO); also elsewhere on the board
SPI_MOSI: J1.19 (GPIO10_SPI_MOSI); also elsewhere on the board
UART_CTS: J1.11 (GPIO17); also elsewhere on the board
UART_RTS: J1.12 (GPIO18); also elsewhere on the board
UART_RX: J1.10 (GPIO15_RXD0); also elsewhere on the board
UART_TX: J1.8 (GPIO14_TXD0); also elsewhere on the board
VDD: J1.2 (5V), J1.4 (5V); also elsewhere on the board

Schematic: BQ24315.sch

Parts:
C18: 100uF; C_1210
IC7: BQ24315; BQ24313_DSG_8
R31: 10K; R_0805
R32: 24K; R_0805
R33: 1M; R_0805
W1: REG_CE; Measurement_Point_Round-SMD-Pad_Small
W2: REG_FAULT; Measurement_Point_Round-SMD-Pad_Small

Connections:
/Proteccion/REG_CE: IC7.5 (~CE), R31.2, W1.1
/Proteccion/REG_FAULT: IC7.4 (~FAULT), R33.1, W2.1
BBB_+3v3: R33.2; also elsewhere on the board
unnamed: IC7.7 (ILIM), R32.2
VCC_AUX: C18.1, IC7.8 (OUT); also elsewhere on the board
VDD_5v: IC7.1 (IN); also elsewhere on the board

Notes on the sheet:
I(limit)=25000/R(limit) 24k =1.04A
Max. 10.5V

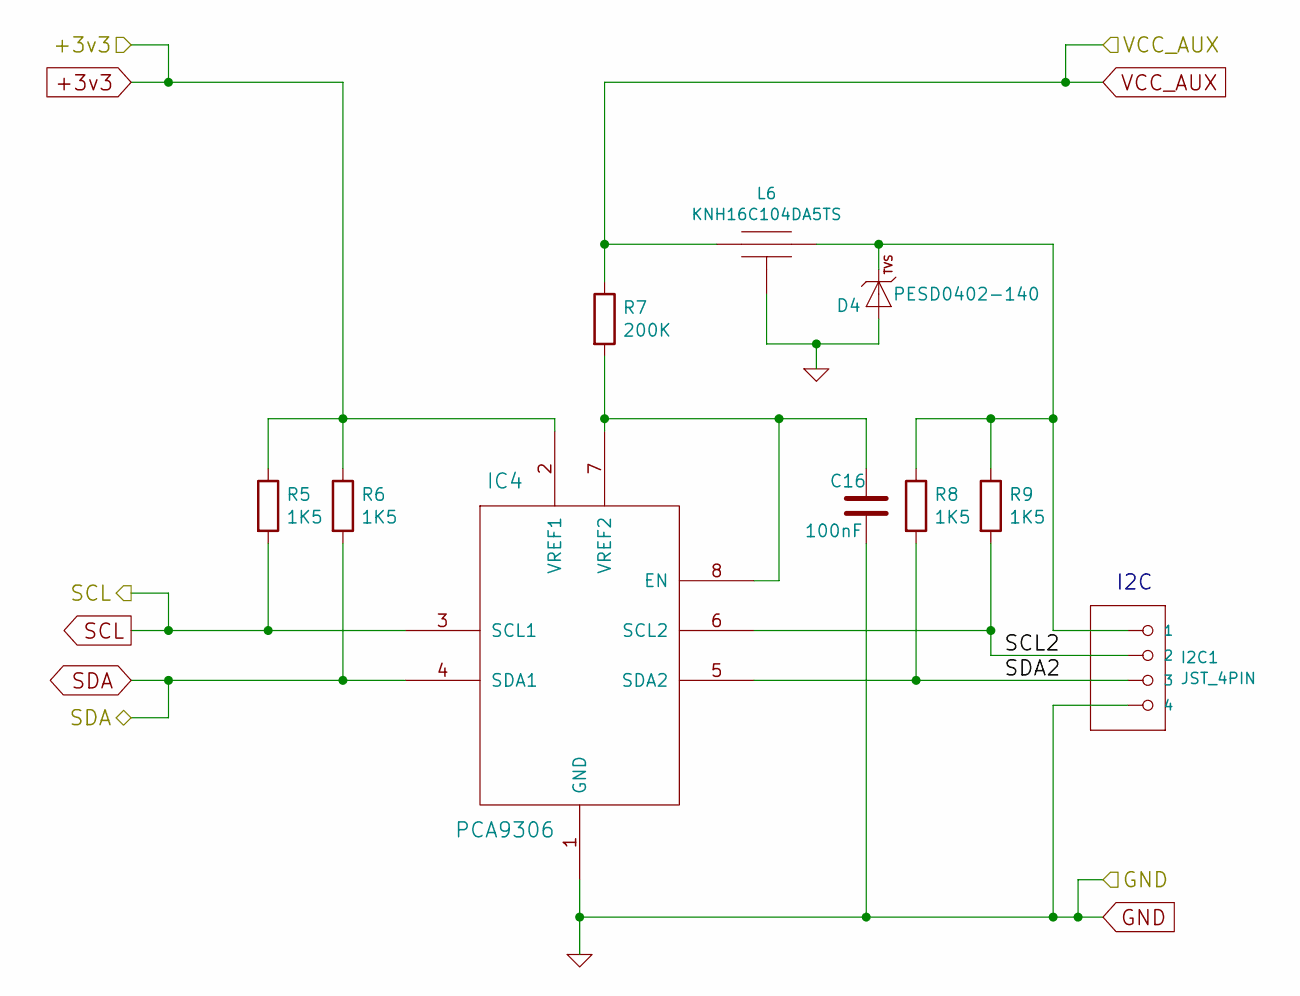
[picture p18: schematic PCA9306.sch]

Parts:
C16: 100nF; C_0805
D4: PESD0402-140; C_0402
I2C1: JST_4PIN; JST_EH_B04B-EH-A_04x2.50mm_Straight
IC4: PCA9306; MSOP-8_3x3mm_Pitch0.65mm
L6: KNH16C104DA5TS; KYOCERA-KNH16-DA
R5, R6, R8, R9: 1K5; R_0805
R7: 200K; R_0805

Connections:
+3v3: IC4.2 (VREF1), R5.1, R6.1; also elsewhere on the board
/I2C/SCL2: I2C1.2, IC4.6 (SCL2), R9.2
/I2C/SDA2: I2C1.3, IC4.5 (SDA2), R8.2
unnamed: C16.1, IC4.7 (VREF2), IC4.8 (EN), R7.2
unnamed: D4.1 (C), I2C1.1, L6.P$2, R8.1, R9.1
SCL: IC4.3 (SCL1), R5.2; also elsewhere on the board
SDA: IC4.4 (SDA1), R6.2; also elsewhere on the board
VCC_AUX: L6.P$1, R7.1; also elsewhere on the board

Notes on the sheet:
I2C

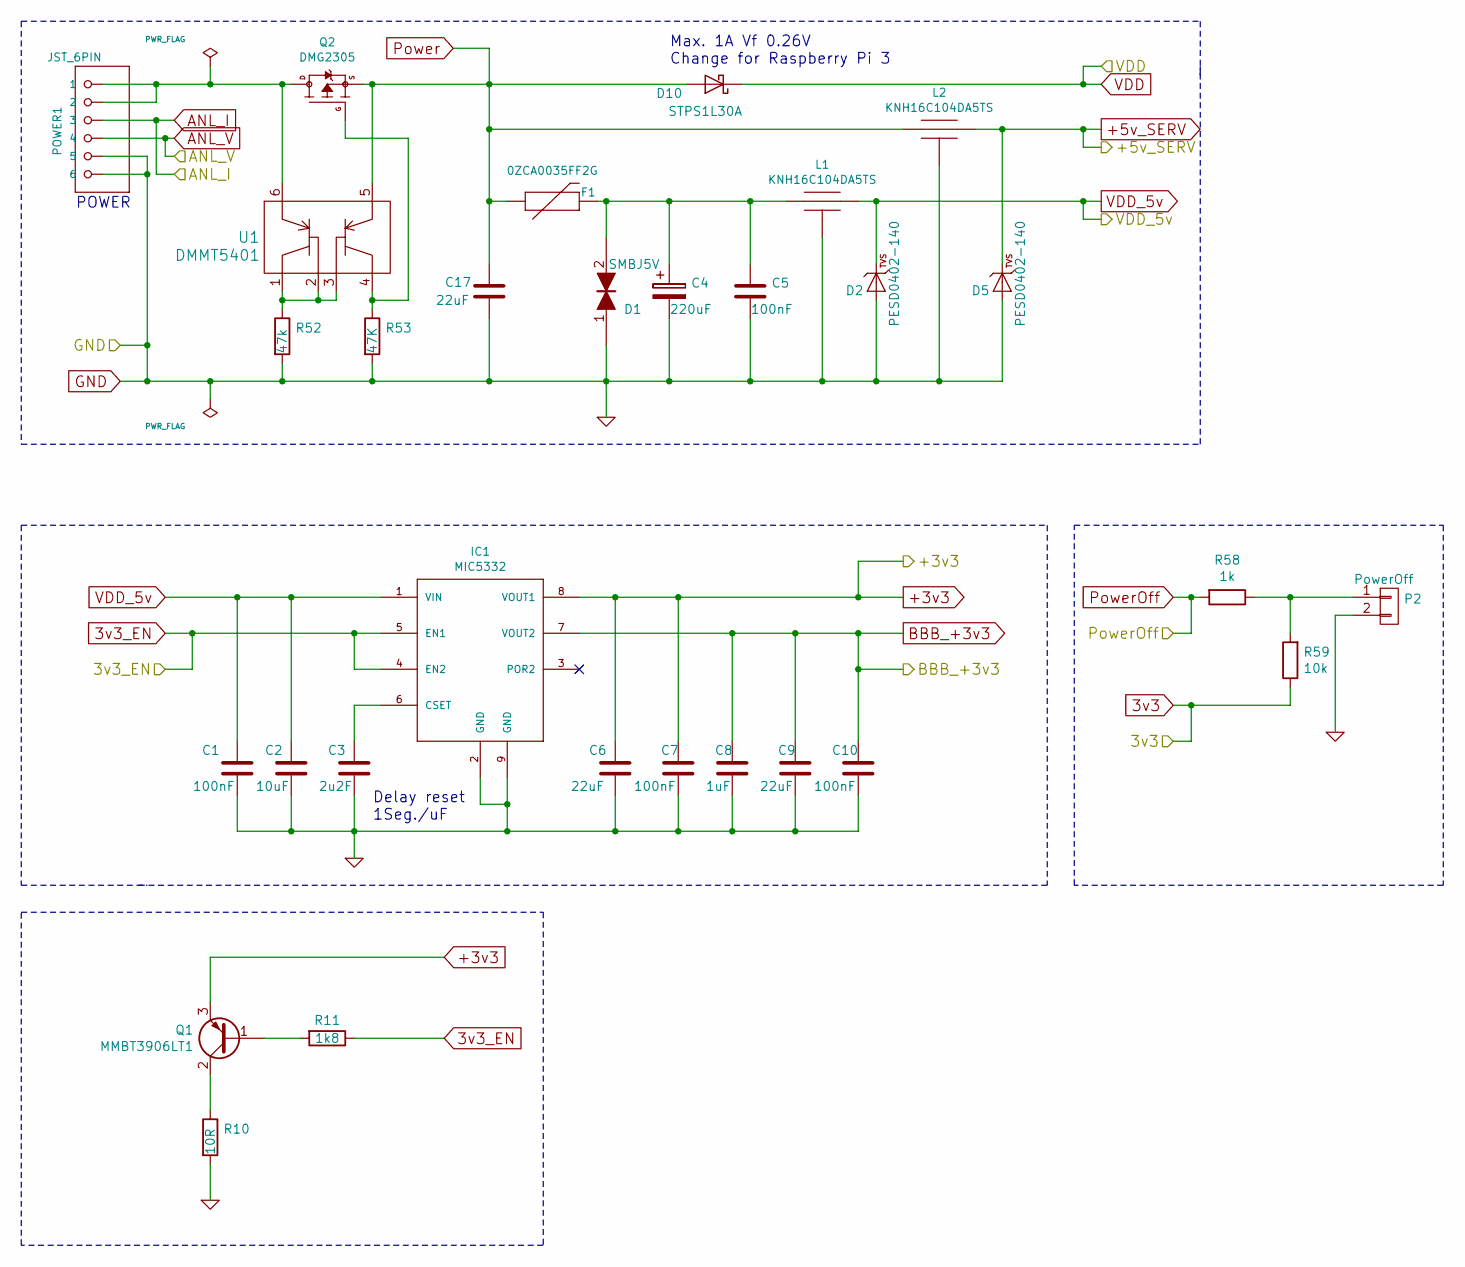
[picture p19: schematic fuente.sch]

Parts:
C1, C5, C7, C10: 100nF; C_0805
C2: 10uF; C_0805
C3: 2u2F; C_0805
C4: 220uF; TantalC_SizeD_EIA-7343_Reflow
C6, C9, C17: 22uF; C_0805
C8: 1uF; C_0805
D1: SMBJ5V; DO-214AA
D2, D5: PESD0402-140; C_0402
D10: STPS1L30A; SMA_Standard
F1: 0ZCA0035FF2G; Fuse_SMD1206_Wave
IC1: MIC5332; MLF-8-1EP
L1, L2: KNH16C104DA5TS; KYOCERA-KNH16-DA
P2: PowerOff; JST_EH_B02B-EH-A_02x2.50mm_Straight
POWER1: JST_6PIN; JST_EH_B06B-EH-A_06x2.50mm_Straight
Q1: MMBT3906LT1; SOT-23
Q2: DMG2305; SOT23-3
R10: 10R; R_0805
R11: 1k8; R_0805
R52: 47k; R_0805
R53: 47K; R_0805
R58: 1k; R_0805
R59: 10k; R_0805
U1: DMMT5401; SOT-23-6

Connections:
3v3: R59.1; also elsewhere on the board
3v3_EN: IC1.4 (EN2), IC1.5 (EN1), R11.1; also elsewhere on the board
+3v3: C6.1, C7.1, IC1.8 (VOUT1), Q1.3 (E); also elsewhere on the board
+5v_SERV: D5.1 (C), L2.P$2; also elsewhere on the board
ANL_I: POWER1.3; also elsewhere on the board
ANL_V: POWER1.4; also elsewhere on the board
BBB_+3v3: C8.1, C9.1, C10.1, IC1.7 (VOUT2); also elsewhere on the board
unnamed: C3.1, IC1.6 (CSET)
unnamed: C4.1, C5.1, D1.2, F1.2, L1.P$1
unnamed: P2.1, R58.1, R59.2
unnamed: POWER1.1, POWER1.2, Q2.3 (D), U1.6
unnamed: Q1.1 (B), R11.2
unnamed: Q1.2 (C), R10.1
unnamed: Q2.1 (G), R53.1, U1.4
unnamed: R52.1, U1.1, U1.2, U1.3
Power: C17.1, D10.2 (A), F1.1, L2.P$1, Q2.2 (S), U1.5
PowerOff: R58.2; also elsewhere on the board
VDD: D10.1 (K); also elsewhere on the board
VDD_5v: C1.1, C2.1, D2.1 (C), IC1.1 (VIN), L1.P$2; also elsewhere on the board

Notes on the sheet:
Delay reset 1Seg./uF
POWER
Max. 1A Vf 0.26V Change for Raspberry Pi 3

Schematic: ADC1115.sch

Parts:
ADC1: CONN_01X02; JST_EH_B02B-EH-A_02x2.50mm_Straight
C15: 100nF; C_0805
IC5: ADC_ADS1115; MSOP-10_3x3mm_Pitch0.5mm
L3, L4: KNH16C104DA5TS; KYOCERA-KNH16-DA
R12, R13: 1M; R_0805
R14, R15, R16, R17, R18, R19, R55, R56: 10K/0.1%; R_0805

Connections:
+3v3: C15.1, IC5.8 (VDD); also elsewhere on the board
ANL_I: L4.P$1, R12.1; also elsewhere on the board
ANL_V: L3.P$1, R13.1; also elsewhere on the board
unnamed: ADC1.1, R55.2
unnamed: ADC1.2, R56.2
unnamed: IC5.4 (AIN0), R14.2, R16.2
unnamed: IC5.5 (AIN1), R15.1, R17.2
unnamed: IC5.6 (AIN2), R55.1
unnamed: IC5.7 (AIN3), R56.1
unnamed: L3.P$2, R14.1
unnamed: L4.P$2, R15.2
unnamed: R16.1, R19.1
unnamed: R17.1, R18.1
SCL: IC5.10 (SCL); also elsewhere on the board
SDA: IC5.9 (SDA); also elsewhere on the board

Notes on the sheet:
AUX. ADC

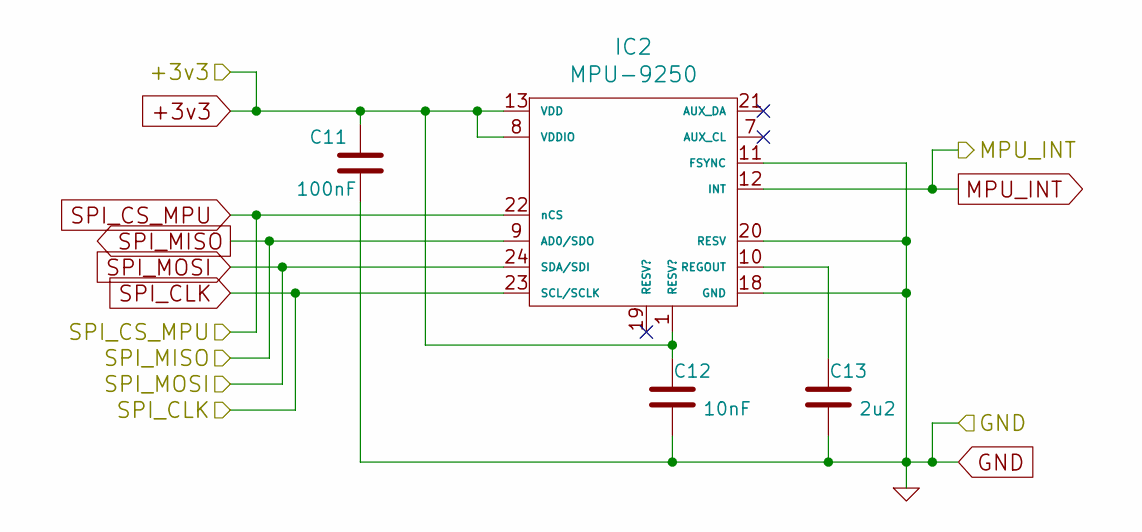
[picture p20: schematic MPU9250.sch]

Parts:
C11: 100nF; C_0805
C12: 10nF; C_0805
C13: 2u2; C_0805
IC2: MPU-9250; QFN-24-1EP_3x3mm_Pitch0.4mm

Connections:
+3v3: C11.1, C12.1, IC2.1 (RESV?), IC2.8 (VDDIO), IC2.13 (VDD); also elsewhere on the board
MPU_INT: IC2.12 (INT); also elsewhere on the board
unnamed: C13.1, IC2.10 (REGOUT)
SPI_CLK: IC2.23 (SCL/SCLK); also elsewhere on the board
SPI_CS_MPU: IC2.22 (nCS); also elsewhere on the board
SPI_MISO: IC2.9 (AD0/SDO); also elsewhere on the board
SPI_MOSI: IC2.24 (SDA/SDI); also elsewhere on the board

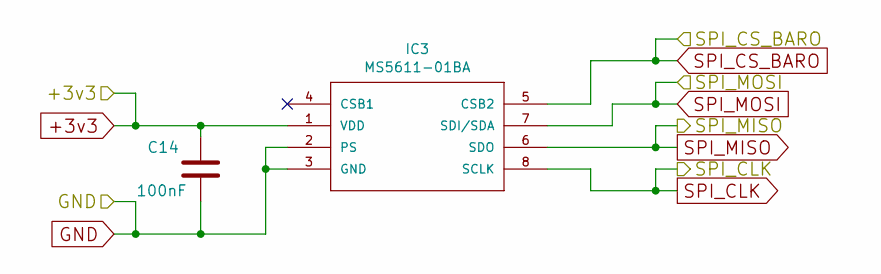
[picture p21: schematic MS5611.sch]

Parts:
C14: 100nF; C_0805
IC3: MS5611-01BA; MS5611

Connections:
+3v3: C14.1, IC3.1 (VDD); also elsewhere on the board
SPI_CLK: IC3.8 (SCLK); also elsewhere on the board
SPI_CS_BARO: IC3.5 (CSB2); also elsewhere on the board
SPI_MISO: IC3.6 (SDO); also elsewhere on the board
SPI_MOSI: IC3.7 (SDI/SDA); also elsewhere on the board

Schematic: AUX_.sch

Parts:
BUZZER1: CONN_01X04; JST_EH_B02B-EH-A_02x2.50mm_Straight
C20, C22: 22pF; C_0805
C21, C23, C24: 100nF; C_0805
CAN-Bus1: JST_4PIN; JST_EH_B04B-EH-A_04x2.50mm_Straight
D6: LED_rojo; LED_0603
D7: LED_verde; LED_0603
D8: LED_azul; LED_0603
D9: PESD0402-140; C_0402
D11: verde; LED_0603
D12: Rojo; LED_0603
D14: LED_naranja; LED_0603
IC8: MCP2515; SOIC-18
IC9: MCP2551; SOIC-8-N
IC10: 24AA32; MSOP-8_3x3mm_Pitch0.65mm
JP1: JUMPER; GS2
JP2: JUMPER3; GS3
L7: KNH16C104DA5TS; KYOCERA-KNH16-DA
Q3: MMBT3906; SOT-23
R34, R35, R60: 680; R_0805
R36: 820; R_0805
R44: 18K; R_0805
R45, R46: 560; R_0805
R47: 10K; R_0805
R48, R54, R61: 1K; R_0805
R49: 120R; R_0805
R50: 3K9; R_0805
R51: 3k9; R_0805
R57: 10k; R_0805
XT2: 16Mhz; HC-18UV

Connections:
3v3: C24.2, IC10.8 (VCC), JP2.1, R50.1, R51.1; also elsewhere on the board
BBB_+3v3: C21.2, IC8.18 (Vdd), R45.1, R46.1, R47.2; also elsewhere on the board
BUZZER: R61.2; also elsewhere on the board
HAT_SCL: IC10.6 (SCL), R50.2; also elsewhere on the board
HAT_SDA: IC10.5 (SDA), R51.2; also elsewhere on the board
INT_CAN: IC8.12 (~INT); also elsewhere on the board
LED_1: R35.2; also elsewhere on the board
LED_2: R36.2; also elsewhere on the board
LED_3: R60.2; also elsewhere on the board
unnamed: BUZZER1.1, R61.1
unnamed: C20.1, IC8.8 (OSC1), XT2.1
unnamed: C22.1, IC8.7 (OSC2), XT2.2
unnamed: C23.1, CAN-Bus1.1, D9.1 (C), IC9.3 (Vdd), L7.P$2
unnamed: CAN-Bus1.2, IC9.7 (CANH), R49.2
unnamed: CAN-Bus1.3, IC9.6 (CANL), JP1.2
unnamed: D6.1, R34.1
unnamed: D7.1, R35.1
unnamed: D8.1, R36.1
unnamed: D11.1 (K), IC8.11 (~RX0BF)
unnamed: D11.2 (A), R45.2
unnamed: D12.1 (K), IC8.10 (~RX1BF)
unnamed: D12.2 (A), R46.2
unnamed: D14.1, R60.1
unnamed: IC8.1 (TXCAN), IC9.1 (TXD)
unnamed: IC8.2 (RXCAN), R44.2, R57.2
unnamed: IC8.17 (~RESET), R47.1
unnamed: IC9.4 (RXD), R57.1
unnamed: IC9.8 (Rs), R48.1
unnamed: IC10.7 (WP), R54.2
unnamed: JP1.1, R49.1
unnamed: JP2.2, R54.1
SPI_CLK: IC8.13 (SCK); also elsewhere on the board
SPI_CS_CAN: IC8.16 (~CS); also elsewhere on the board
SPI_MISO: IC8.15 (SO); also elsewhere on the board
SPI_MOSI: IC8.14 (SI); also elsewhere on the board
VCC_AUX: D6.2, D7.2, D8.2, D14.2, L7.P$1; also elsewhere on the board

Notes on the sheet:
CAN Bus
AUX. Buzzer

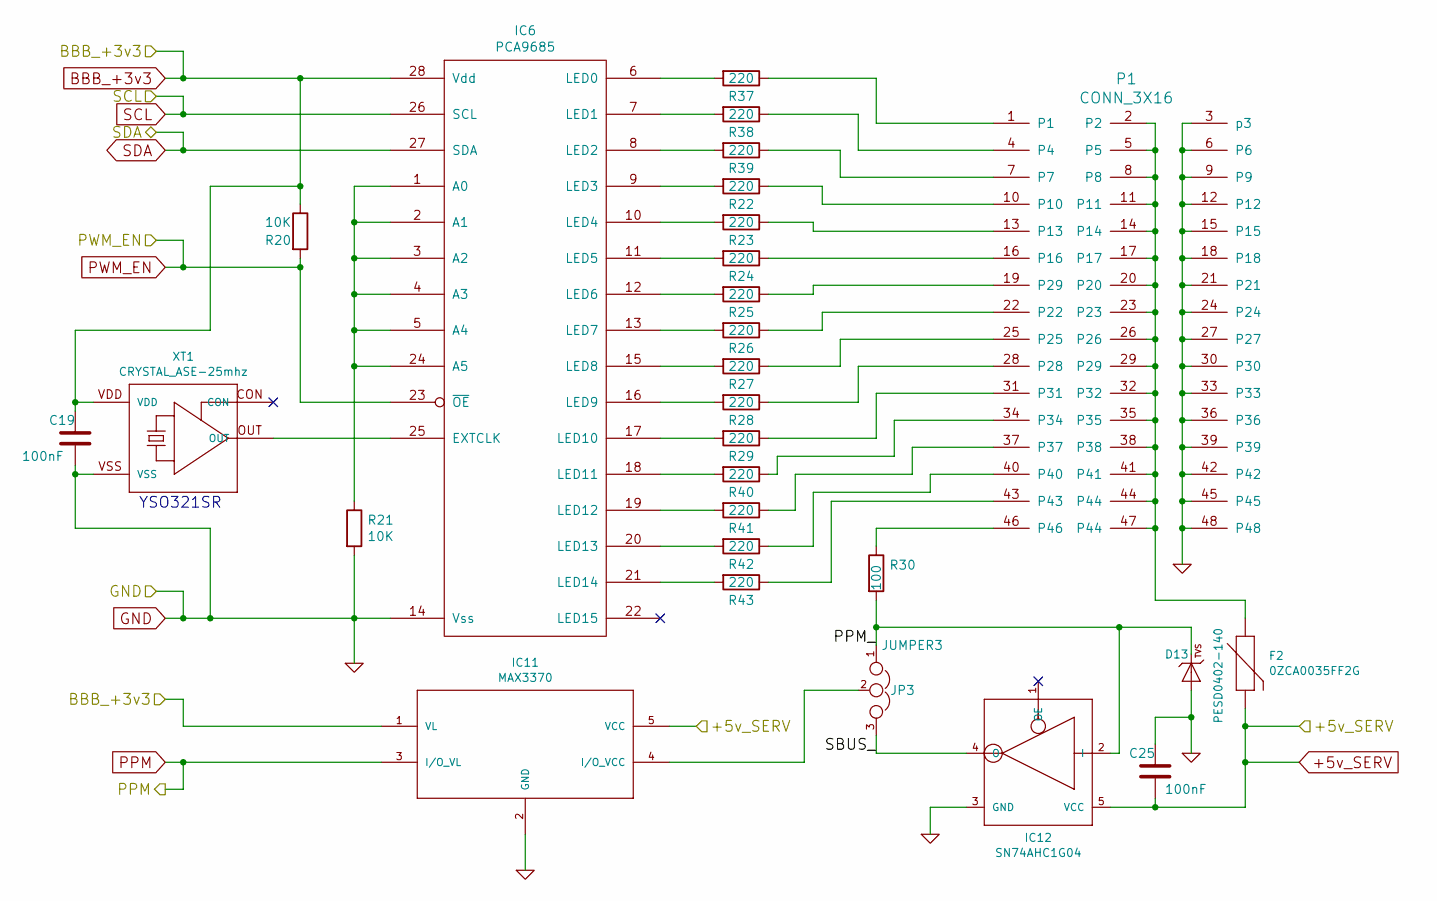
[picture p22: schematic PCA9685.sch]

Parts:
C19, C25: 100nF; C_0805
D13: PESD0402-140; C_0402
F2: 0ZCA0035FF2G; Fuse_SMD1206_Wave
IC6: PCA9685; TSSOP-28_4.4x9.7mm_Pitch0.65mm
IC11: MAX3370; SC70-5
IC12: SN74AHC1G04; SC70-5
JP3: JUMPER3; GS3
P1: CONN_3X16; IDC_Header_Straight_48pins
R20, R21: 10K; R_0805
R22, R23, R24, R25, R26, R27, R28, R29, R37, R38, R39, R40, R41, R42, R43: 220; R_0805
R30: 100; R_0805
XT1: CRYSTAL_ASE-25mhz; ASEseries

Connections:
+5v_SERV: C25.2, F2.2, IC11.5 (VCC), IC12.5 (VCC); also elsewhere on the board
/PWM-PPM-SBUS/PPM_: D13.1 (C), IC12.2 (I), JP3.1, R30.2
/PWM-PPM-SBUS/SBUS_: IC12.4 (O), JP3.3
BBB_+3v3: C19.1, IC6.28 (Vdd), IC11.1 (VL), R20.1, XT1.4 (VDD); also elsewhere on the board
unnamed: F2.1, P1.2, P1.5, P1.8, P1.11, P1.14, P1.17, P1.20, P1.23, P1.26, P1.29, P1.32, P1.35, P1.38, P1.41, P1.44, P1.47 (P44)
unnamed: IC6.1 (A0), IC6.2 (A1), IC6.3 (A2), IC6.4 (A3), IC6.5 (A4), IC6.24 (A5), R21.1
unnamed: IC6.6 (LED0), R37.2
unnamed: IC6.7 (LED1), R38.2
unnamed: IC6.8 (LED2), R39.2
unnamed: IC6.9 (LED3), R22.2
unnamed: IC6.10 (LED4), R23.2
unnamed: IC6.11 (LED5), R24.2
unnamed: IC6.12 (LED6), R25.2
unnamed: IC6.13 (LED7), R26.2
unnamed: IC6.15 (LED8), R27.2
unnamed: IC6.16 (LED9), R28.2
unnamed: IC6.17 (LED10), R29.2
unnamed: IC6.18 (LED11), R40.2
unnamed: IC6.19 (LED12), R41.2
unnamed: IC6.20 (LED13), R42.2
unnamed: IC6.21 (LED14), R43.2
unnamed: IC6.25 (EXTCLK), XT1.3 (OUT)
unnamed: IC11.4 (I/O_VCC), JP3.2
unnamed: P1.1, R37.1
unnamed: P1.4, R38.1
unnamed: P1.7, R39.1
unnamed: P1.10, R22.1
unnamed: P1.13, R23.1
unnamed: P1.16, R24.1
unnamed: P1.19 (P29), R25.1
unnamed: P1.22, R26.1
unnamed: P1.25, R27.1
unnamed: P1.28, R28.1
unnamed: P1.31, R29.1
unnamed: P1.34, R40.1
unnamed: P1.37, R41.1
unnamed: P1.40, R42.1
unnamed: P1.43, R43.1
unnamed: P1.46, R30.1
PPM: IC11.3 (I/O_VL); also elsewhere on the board
PWM_EN: IC6.23 (~OE), R20.2; also elsewhere on the board
SCL: IC6.26 (SCL); also elsewhere on the board
SDA: IC6.27 (SDA); also elsewhere on the board

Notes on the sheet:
YSO321SR

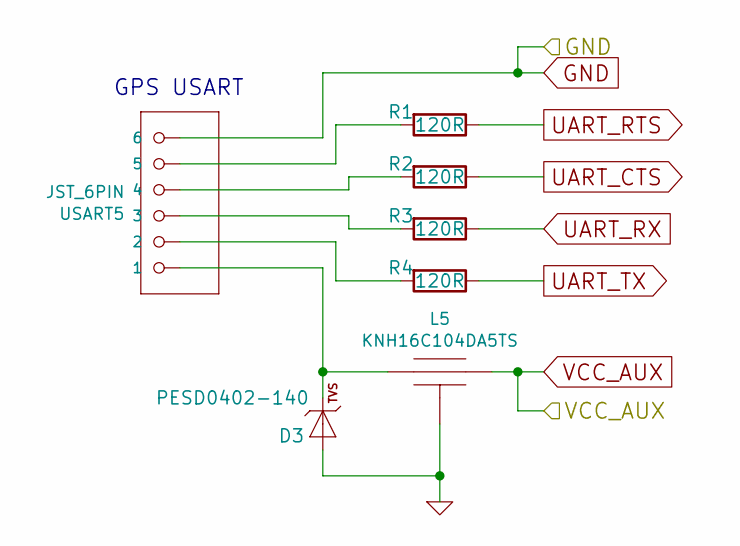
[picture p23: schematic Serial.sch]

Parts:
D3: PESD0402-140; C_0402
L5: KNH16C104DA5TS; KYOCERA-KNH16-DA
R1, R2, R3, R4: 120R; R_0805
USART5: JST_6PIN; JST_EH_B06B-EH-A_06x2.50mm_Straight

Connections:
unnamed: D3.1 (C), L5.P$1, USART5.1
unnamed: R1.2, USART5.5
unnamed: R2.2, USART5.4
unnamed: R3.2, USART5.3
unnamed: R4.2, USART5.2
UART_CTS: R2.1; also elsewhere on the board
UART_RTS: R1.1; also elsewhere on the board
UART_RX: R3.1; also elsewhere on the board
UART_TX: R4.1; also elsewhere on the board
VCC_AUX: L5.P$2; also elsewhere on the board

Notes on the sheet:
GPS USART

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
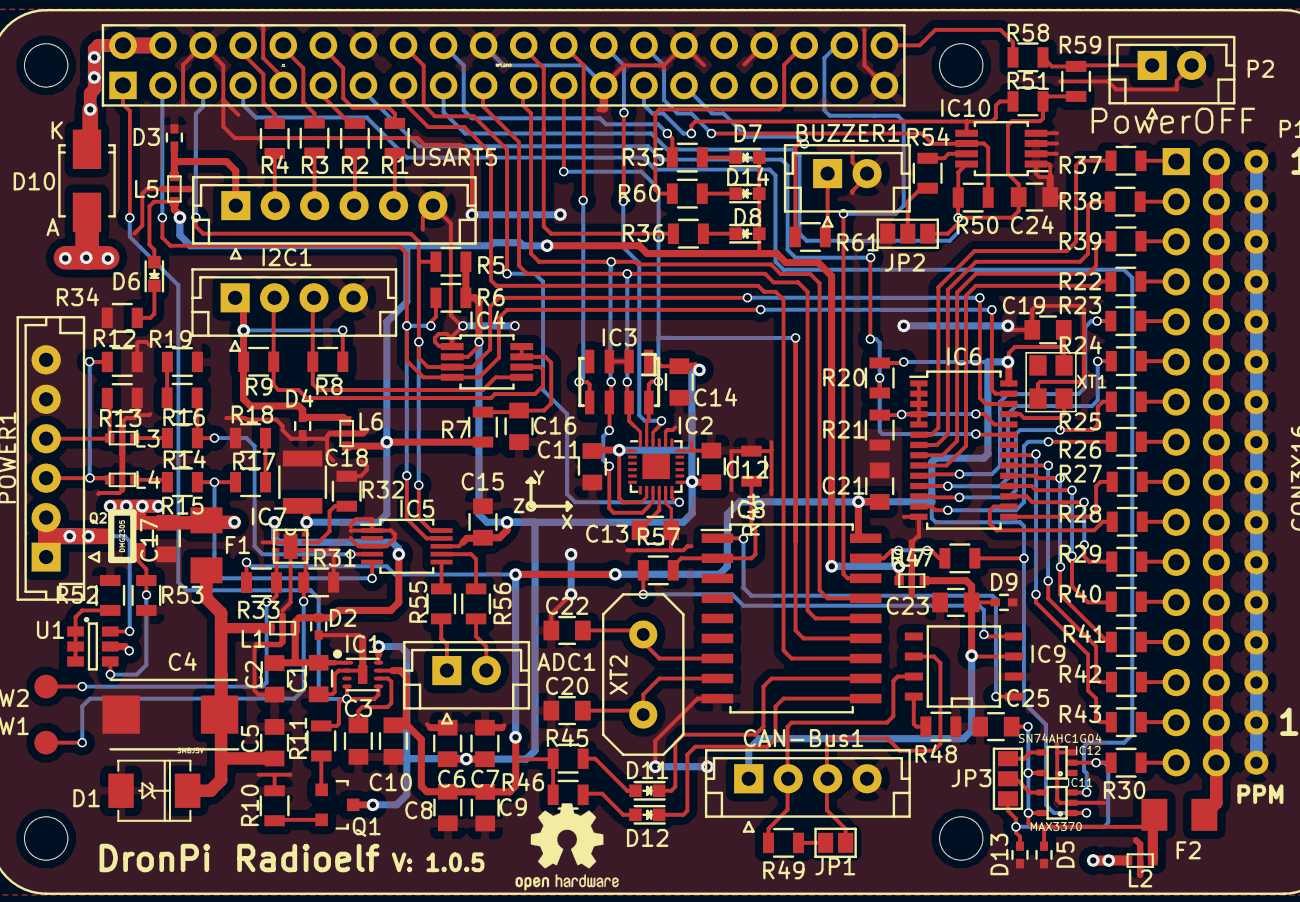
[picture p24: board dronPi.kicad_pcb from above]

Board: 2 copper layers, 141 parts (0 on the bottom side), 125 nets.

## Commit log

2016-10-01 3D pcb DronPi v1.0.4
    Vista de la placa DronPi en 3D con Kicad
2016-10-02 Imagen de la placa en 3d según Kicad
2016-10-02 Create Ficheros PCB
2016-10-02 Create Ficheros gerber
2016-10-02 Update Ficheros PCB
2016-10-02 GPIO Raspberry for DronPi
2016-10-03 Imágen de la placa (1.0.2)
2016-10-14 PCB v1.0.5
2016-11-22 PCB 1.0.5
2017-01-25 PCB v1.0.5 Mounted

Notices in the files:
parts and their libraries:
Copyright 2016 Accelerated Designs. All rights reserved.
